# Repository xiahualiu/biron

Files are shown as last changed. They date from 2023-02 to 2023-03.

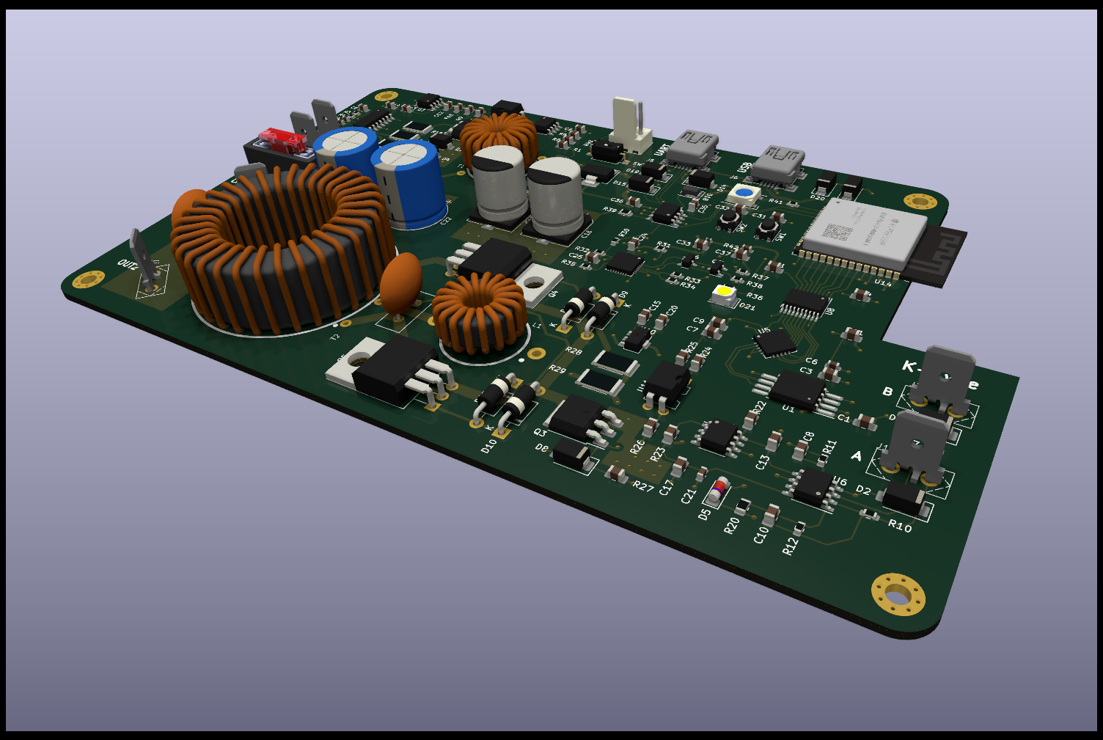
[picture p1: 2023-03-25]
KiCAD/3d/biron.png

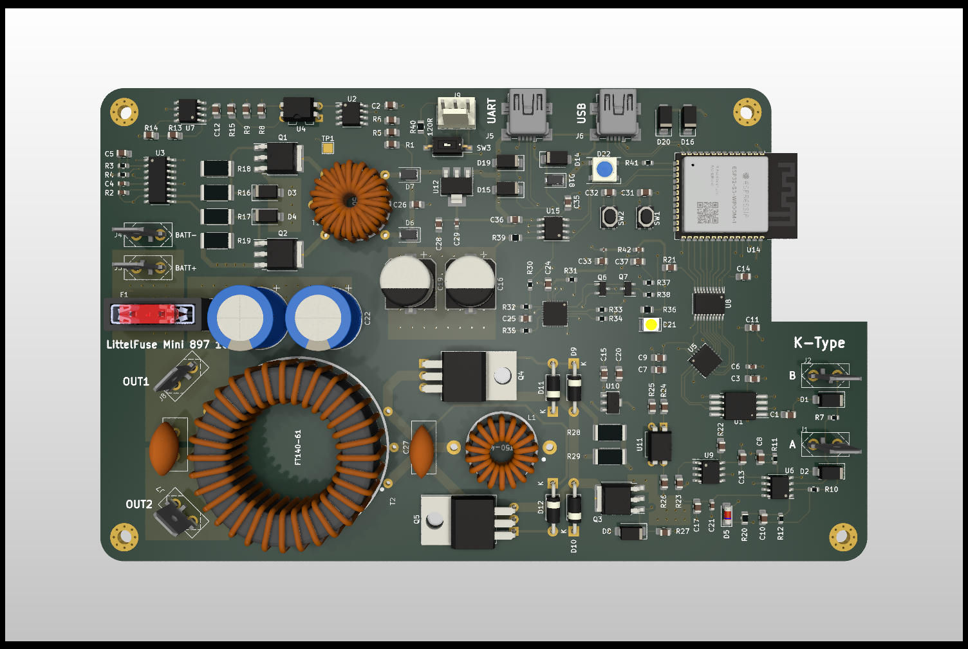
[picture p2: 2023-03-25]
KiCAD/3d/biron-top.png

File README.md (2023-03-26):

# biron

Biron is an open source soldering iron hardware based on Baxandall Oscillator. This is a homebrew project that I am doing during the free time at home.

## Software Requirements

* KiCAD v7.0.0 or above to view the schematic and PCB files.
* LTSpice 17.1.6.0 or above to view the SPICE simulation.

## Disclaimer

This is an open source project that involves high voltage and hot surfaces. You must have enough experience to build it in real life and wear PPE, I don't want people get hurt.

result





This project follows the Ti's [DAQ system requirements](https://www.ti.com/solution/data-acquisition-daq), the control system is fully galvanized isolated from the physical and power signals.



### Power isolation

I used a minimal push-pull converter for the DC/DC part:



### Sensor signal isolation

Sensor signals are amplifier through a TL082H (not practical in the real world because of the high Vos, you want Vos<100uV if possible). The signal is read by a RV1S9353A from Renesas.



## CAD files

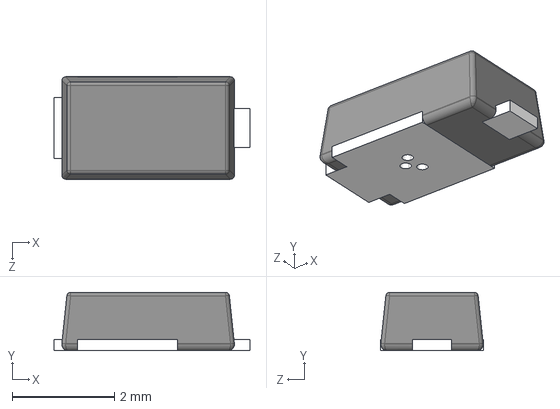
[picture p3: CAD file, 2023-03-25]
KiCAD/3d/SS3P6HM3_85A.STEP
3.83 x 1.14 x 2.00 mm

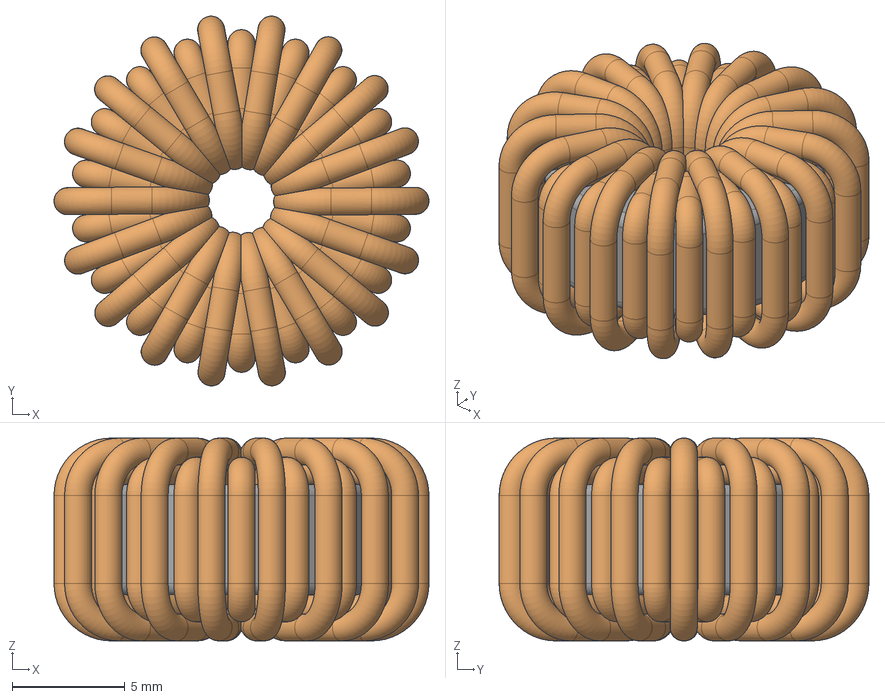
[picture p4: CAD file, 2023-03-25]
KiCAD/3d/FT50-75.step
16.6 x 16.4 x 9.00 mm

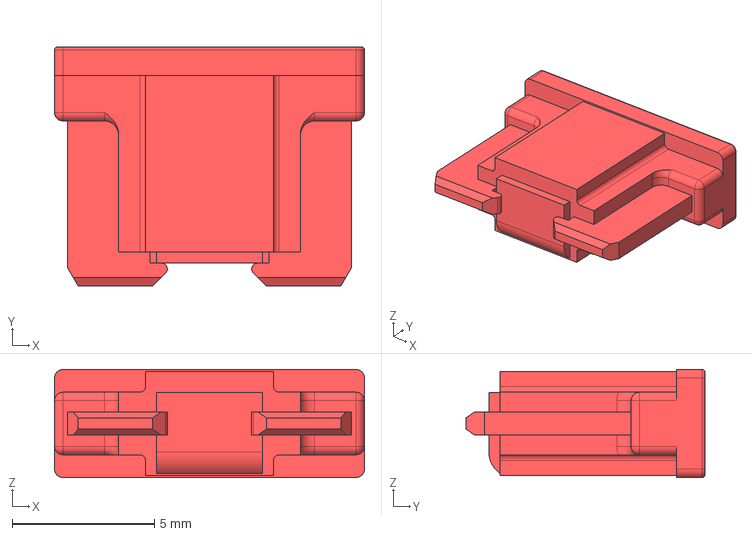
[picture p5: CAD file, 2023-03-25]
KiCAD/3d/Red-3DMODEL_0891000_LPMINI.step
10.9 x 8.40 x 3.80 mm

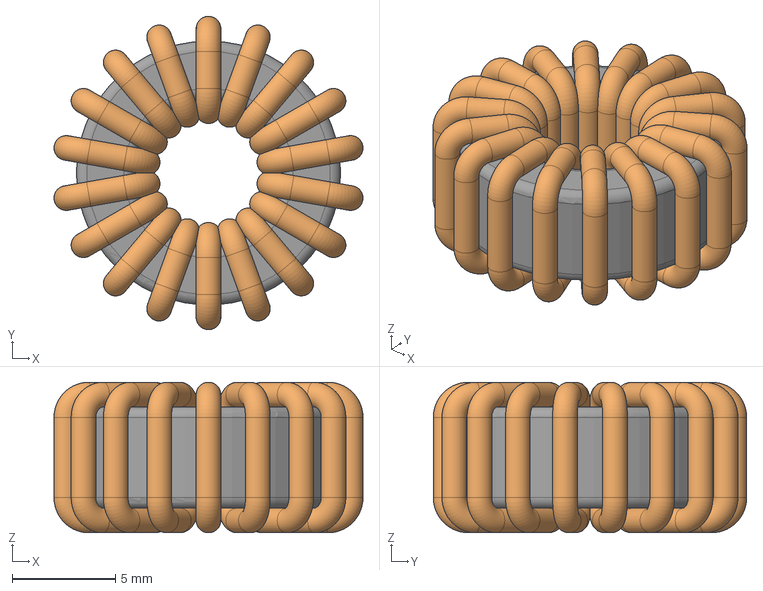
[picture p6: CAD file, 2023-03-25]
KiCAD/3d/FT50-43.step
15.0 x 15.2 x 7.30 mm

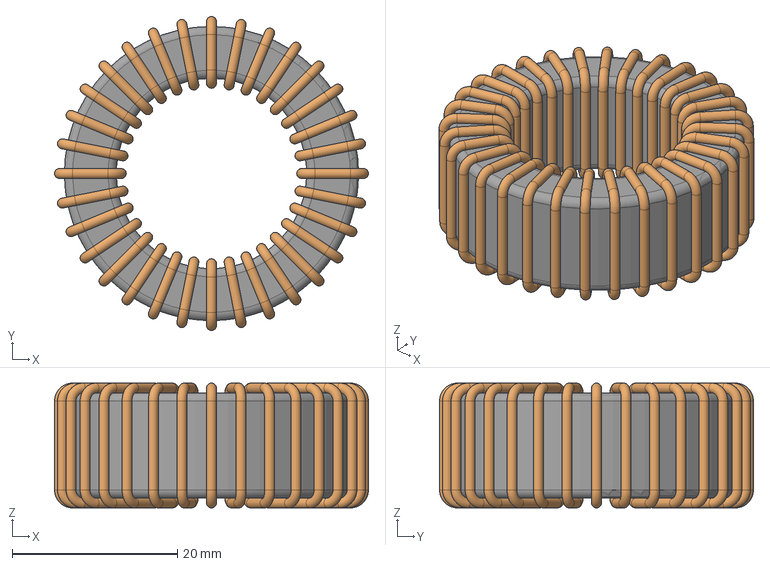
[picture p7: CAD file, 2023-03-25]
KiCAD/3d/FT140-61.step
38.0 x 38.0 x 15.1 mm

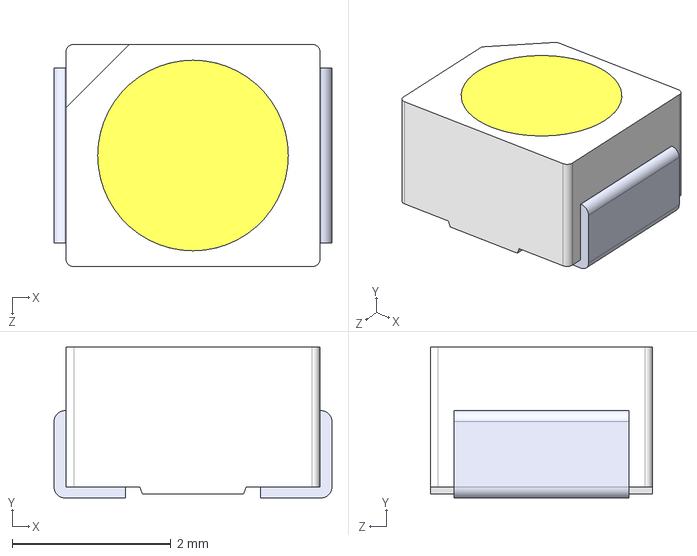
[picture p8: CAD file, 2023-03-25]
KiCAD/3d/OF-SMD3528WC--3DModel-STEP-269445.STEP
3.50 x 1.90 x 2.80 mm

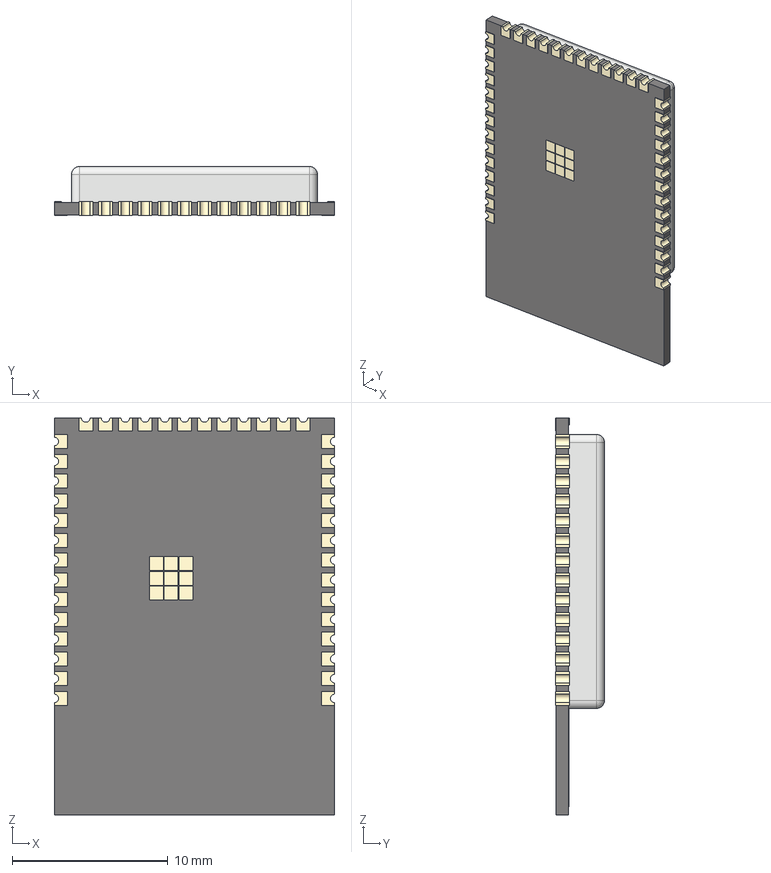
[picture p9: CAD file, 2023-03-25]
KiCAD/3d/ESP32-S3-WROOM.step
18.0 x 3.16 x 25.5 mm
ESP-S3-WROOM_via x 26
ESP32-S3-WROOM_shell
ESP32-S3-WROOM_body
ESP-S3-WROOM_via v3(镜像) x 14

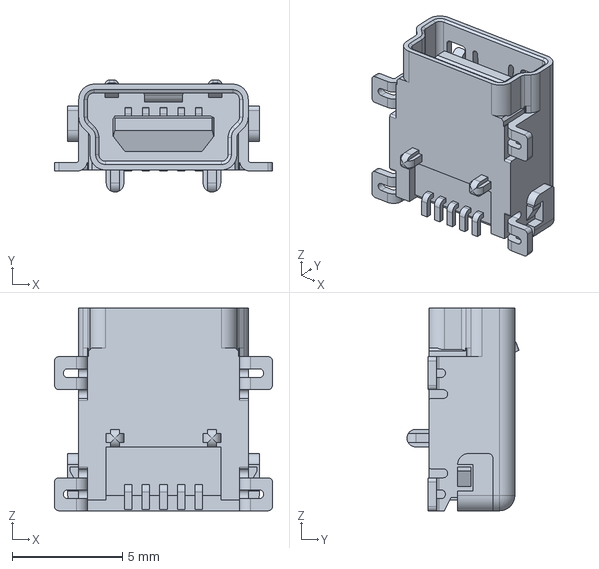
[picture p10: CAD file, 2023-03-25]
KiCAD/3d/3-1734035-2.stp
9.90 x 5.09 x 9.20 mm

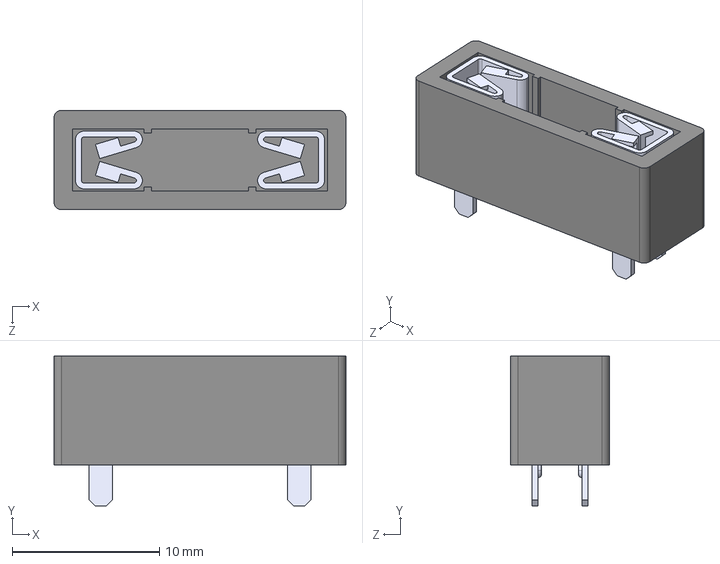
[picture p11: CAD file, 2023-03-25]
KiCAD/3d/3557-2.step
19.8 x 10.2 x 6.73 mm

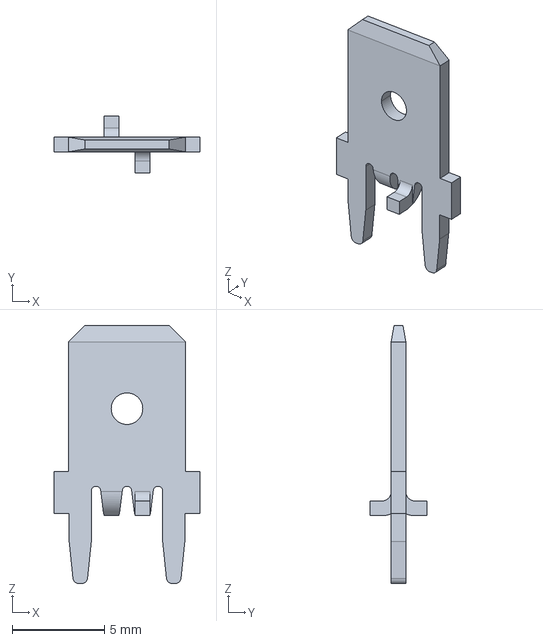
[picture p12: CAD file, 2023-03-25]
KiCAD/3d/63824-1--3DModel-STEP-1.STEP
7.92 x 3.09 x 14.0 mm

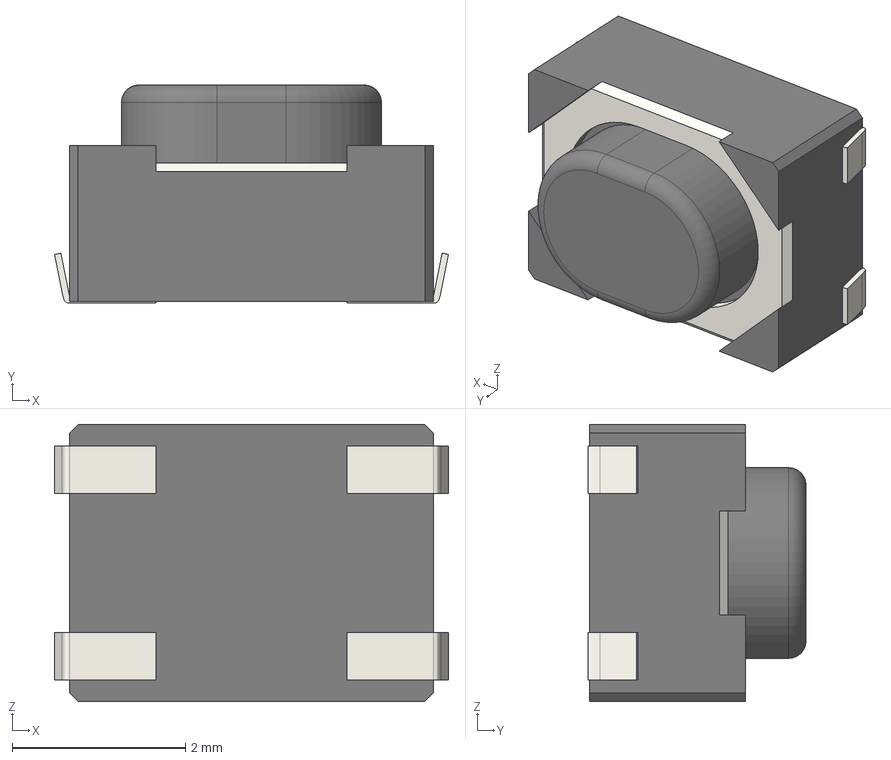
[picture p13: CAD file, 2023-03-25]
KiCAD/3d/434133025816--3DModel-STEP-209312.STEP
4.55 x 2.52 x 3.20 mm

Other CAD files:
KiCAD/3d/3D_model_0891000_LP_MINI_58V.stp
KiCAD/3d/FT140-61.FCStd
KiCAD/3d/FT50-43.FCStd
KiCAD/3d/FT50-75.FCStd

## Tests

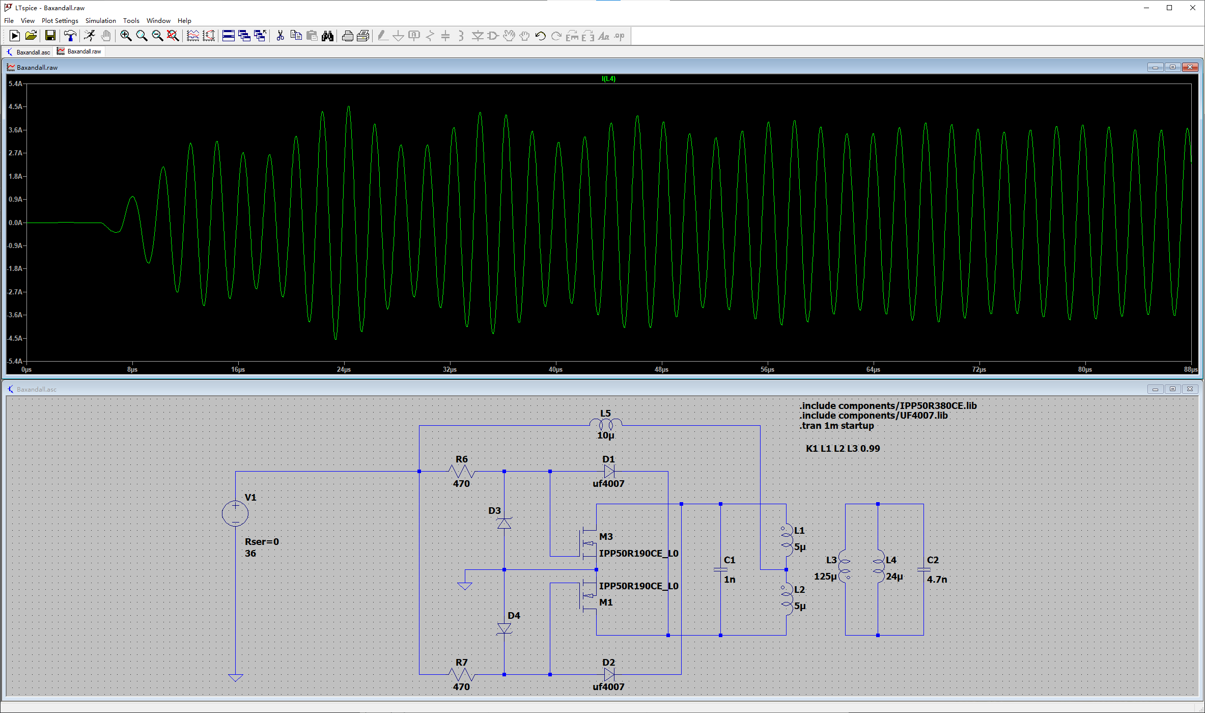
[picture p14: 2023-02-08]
LTSpice/result.png

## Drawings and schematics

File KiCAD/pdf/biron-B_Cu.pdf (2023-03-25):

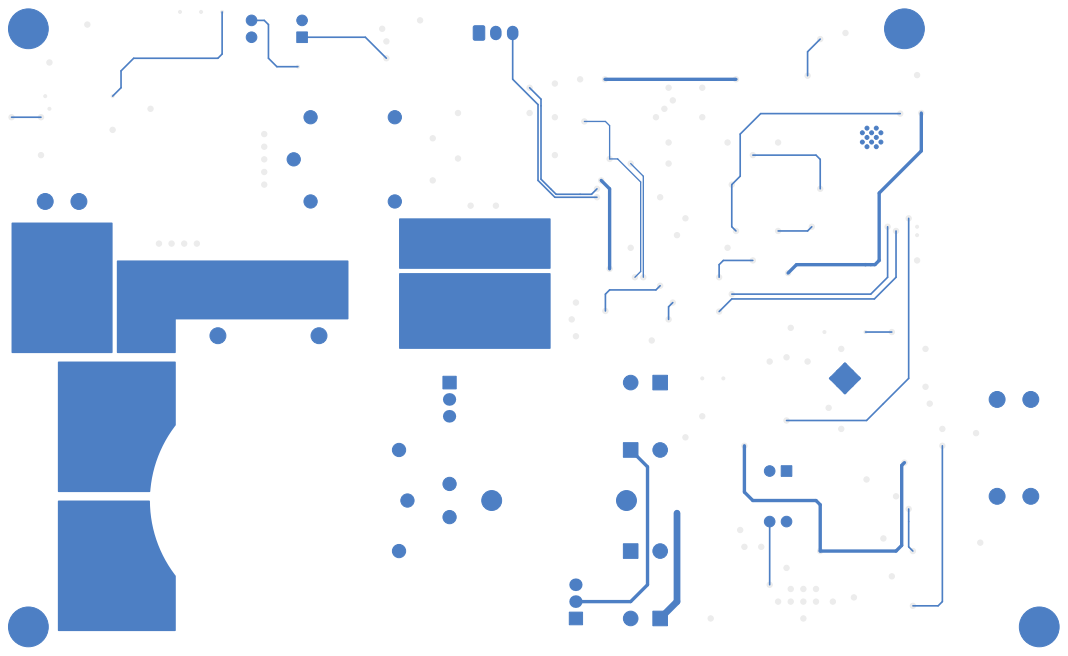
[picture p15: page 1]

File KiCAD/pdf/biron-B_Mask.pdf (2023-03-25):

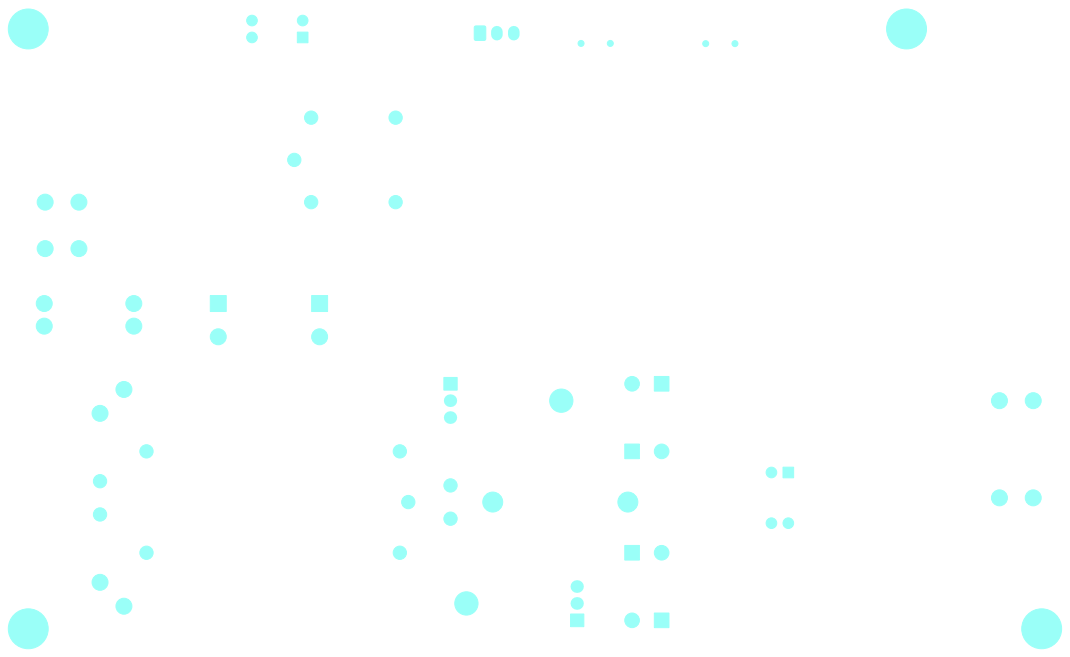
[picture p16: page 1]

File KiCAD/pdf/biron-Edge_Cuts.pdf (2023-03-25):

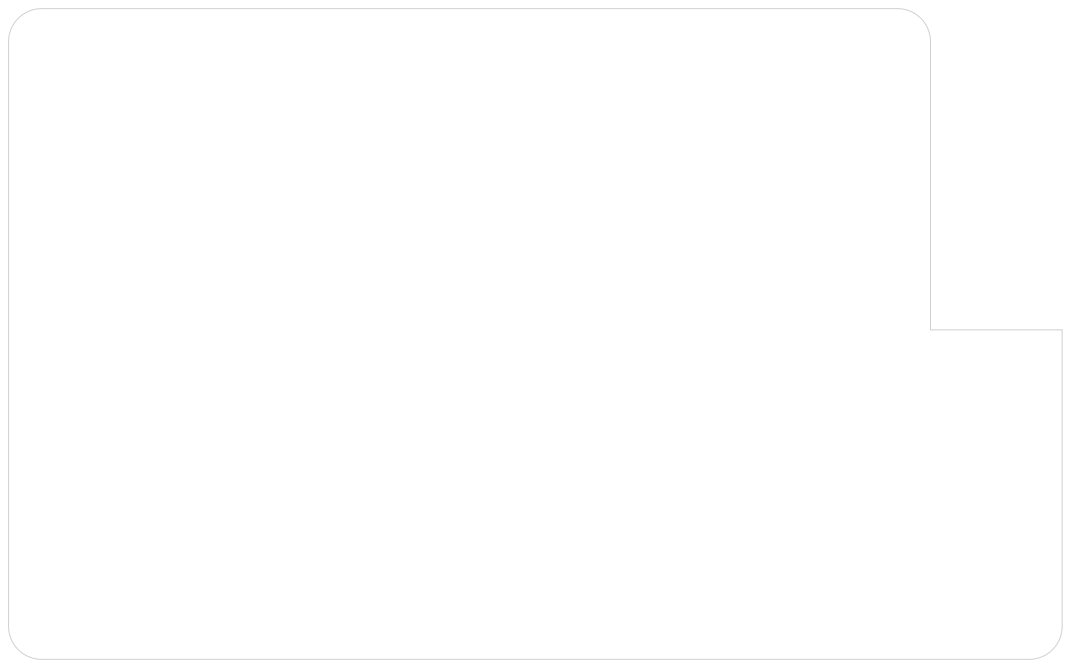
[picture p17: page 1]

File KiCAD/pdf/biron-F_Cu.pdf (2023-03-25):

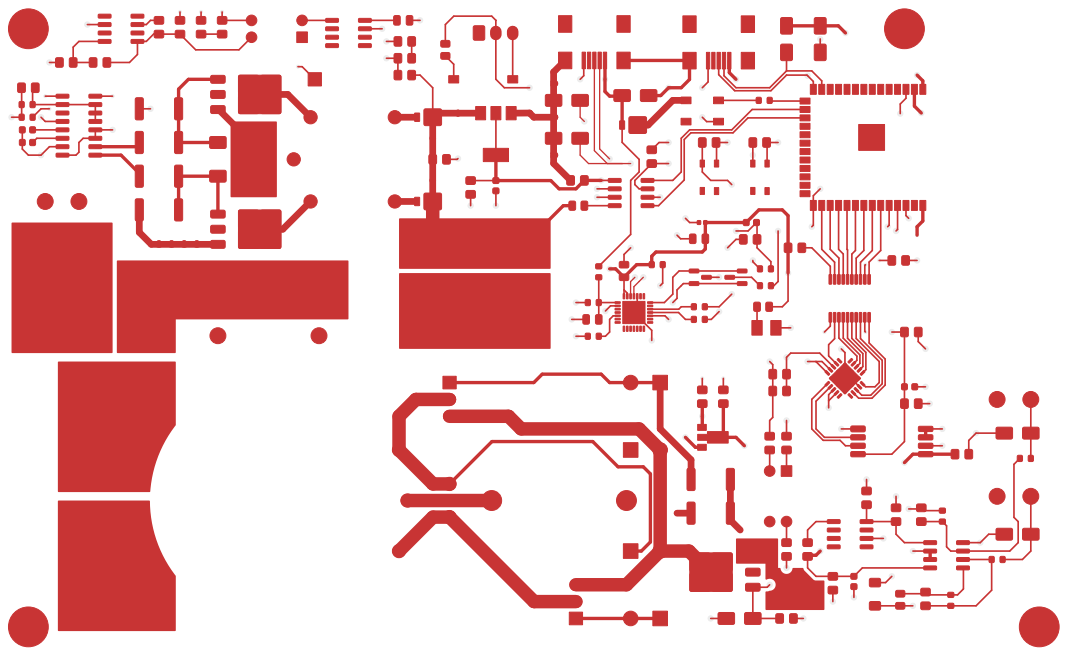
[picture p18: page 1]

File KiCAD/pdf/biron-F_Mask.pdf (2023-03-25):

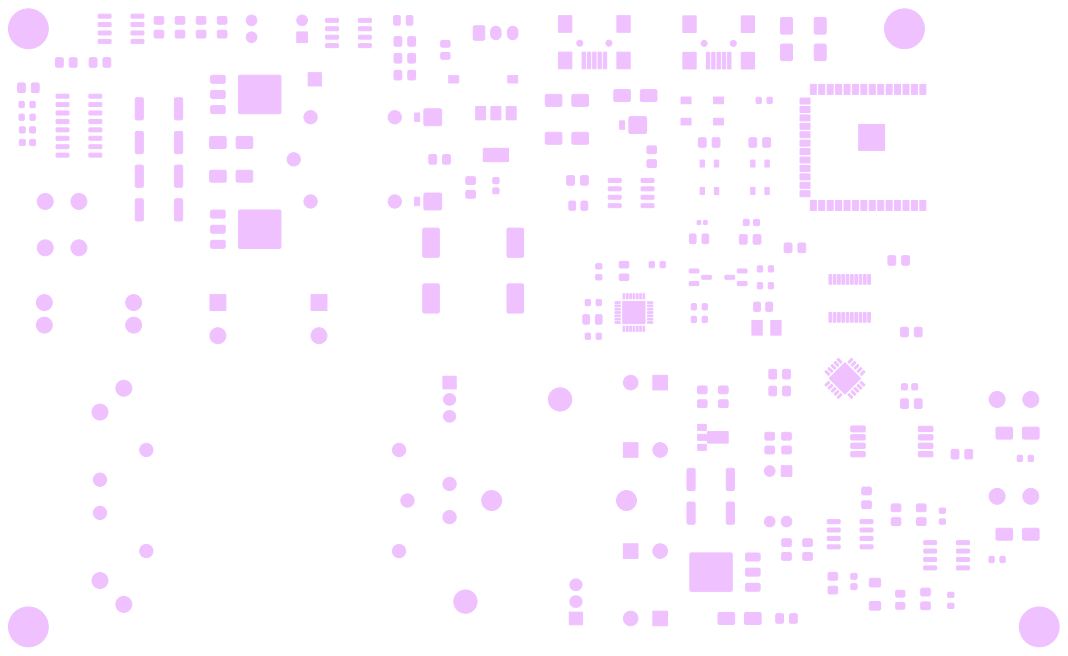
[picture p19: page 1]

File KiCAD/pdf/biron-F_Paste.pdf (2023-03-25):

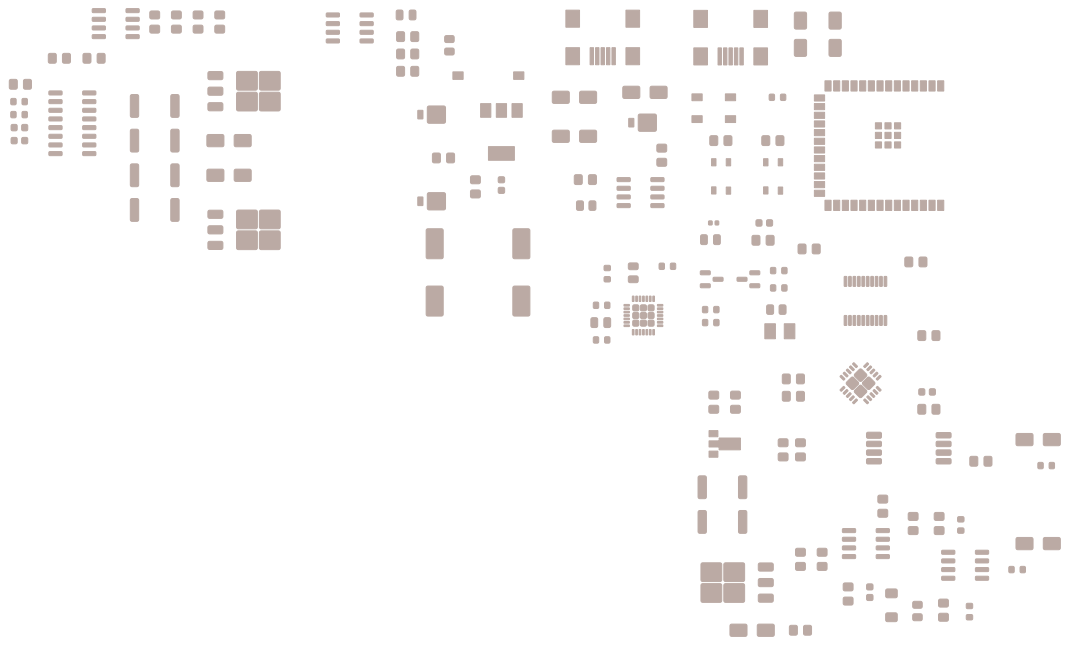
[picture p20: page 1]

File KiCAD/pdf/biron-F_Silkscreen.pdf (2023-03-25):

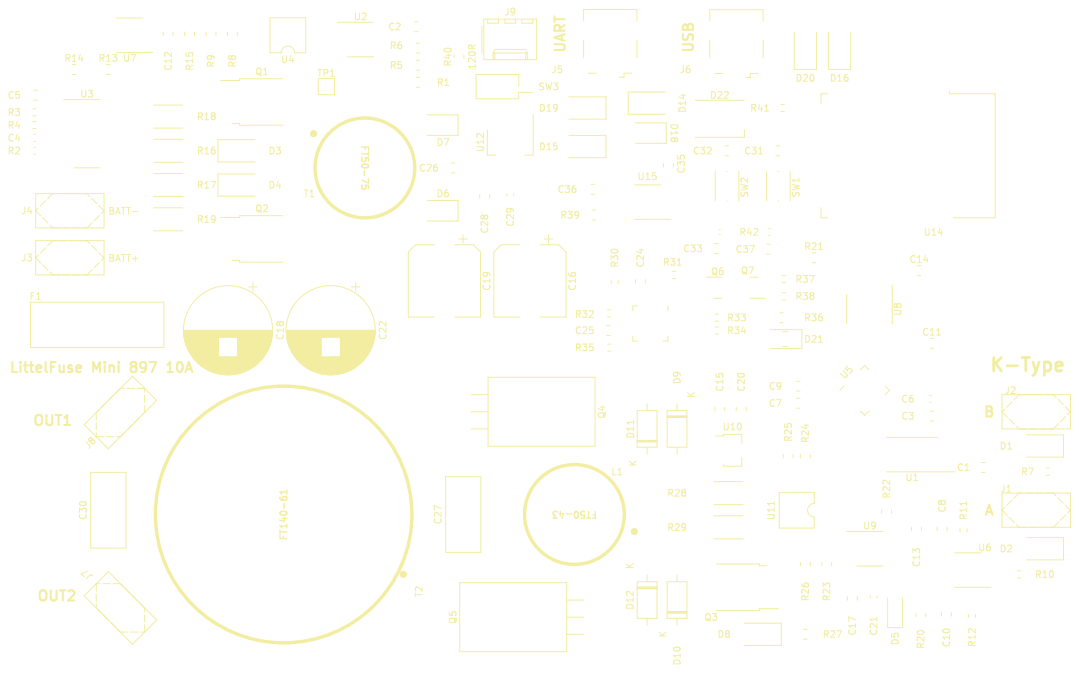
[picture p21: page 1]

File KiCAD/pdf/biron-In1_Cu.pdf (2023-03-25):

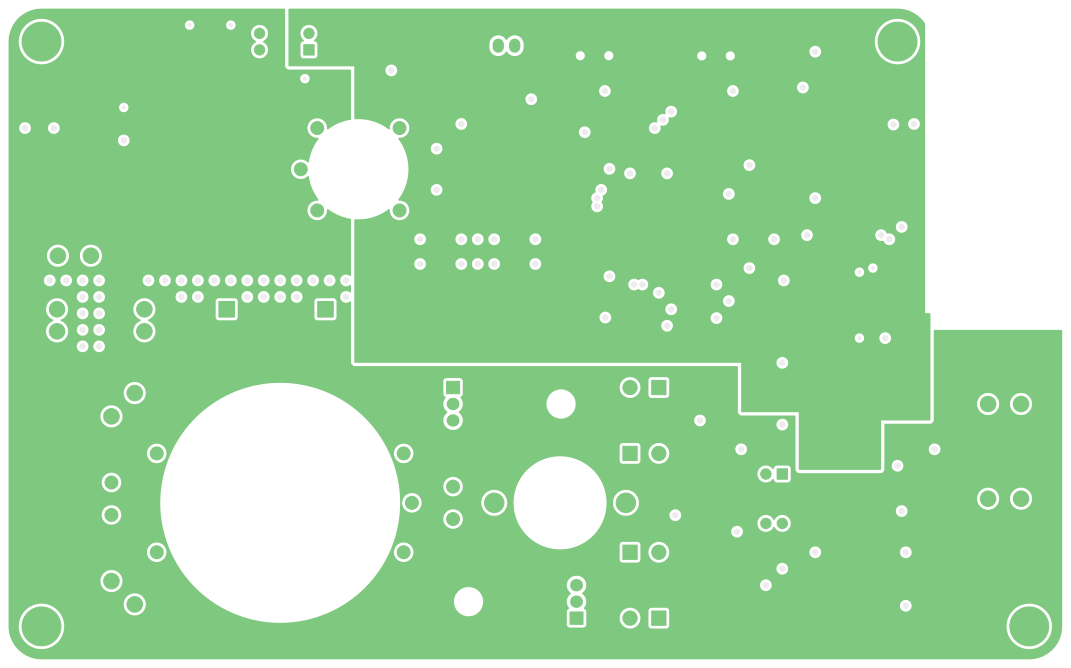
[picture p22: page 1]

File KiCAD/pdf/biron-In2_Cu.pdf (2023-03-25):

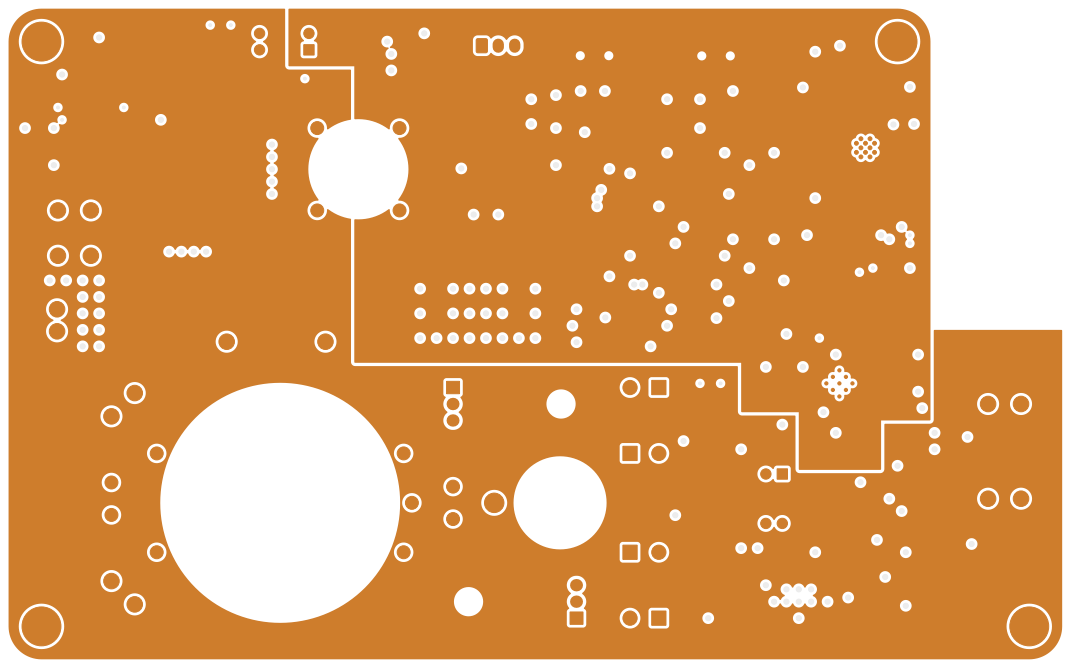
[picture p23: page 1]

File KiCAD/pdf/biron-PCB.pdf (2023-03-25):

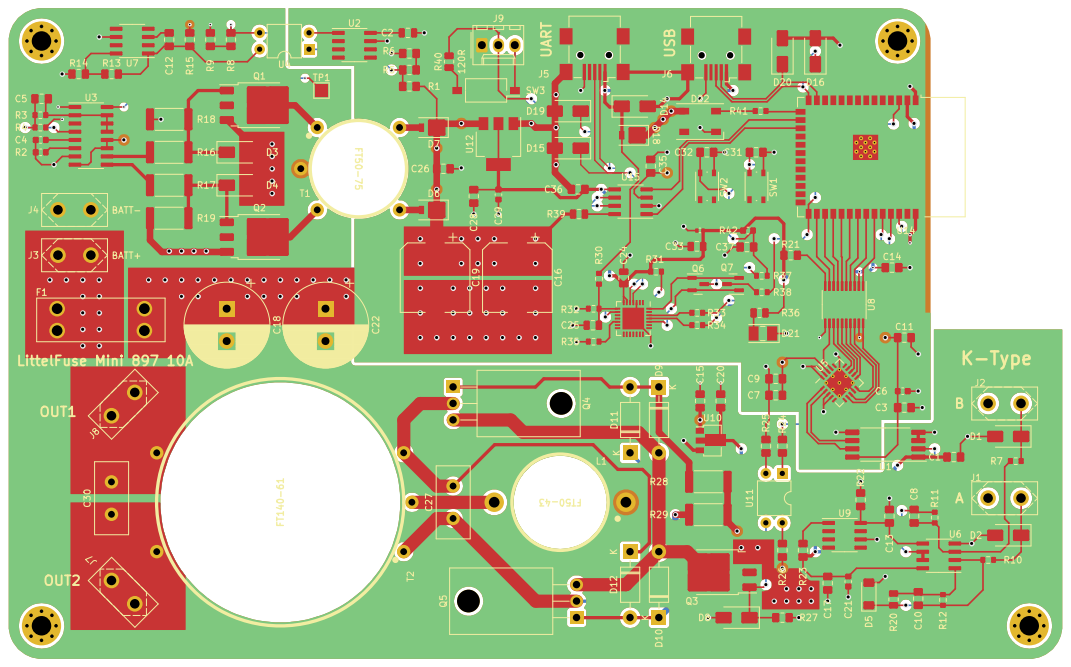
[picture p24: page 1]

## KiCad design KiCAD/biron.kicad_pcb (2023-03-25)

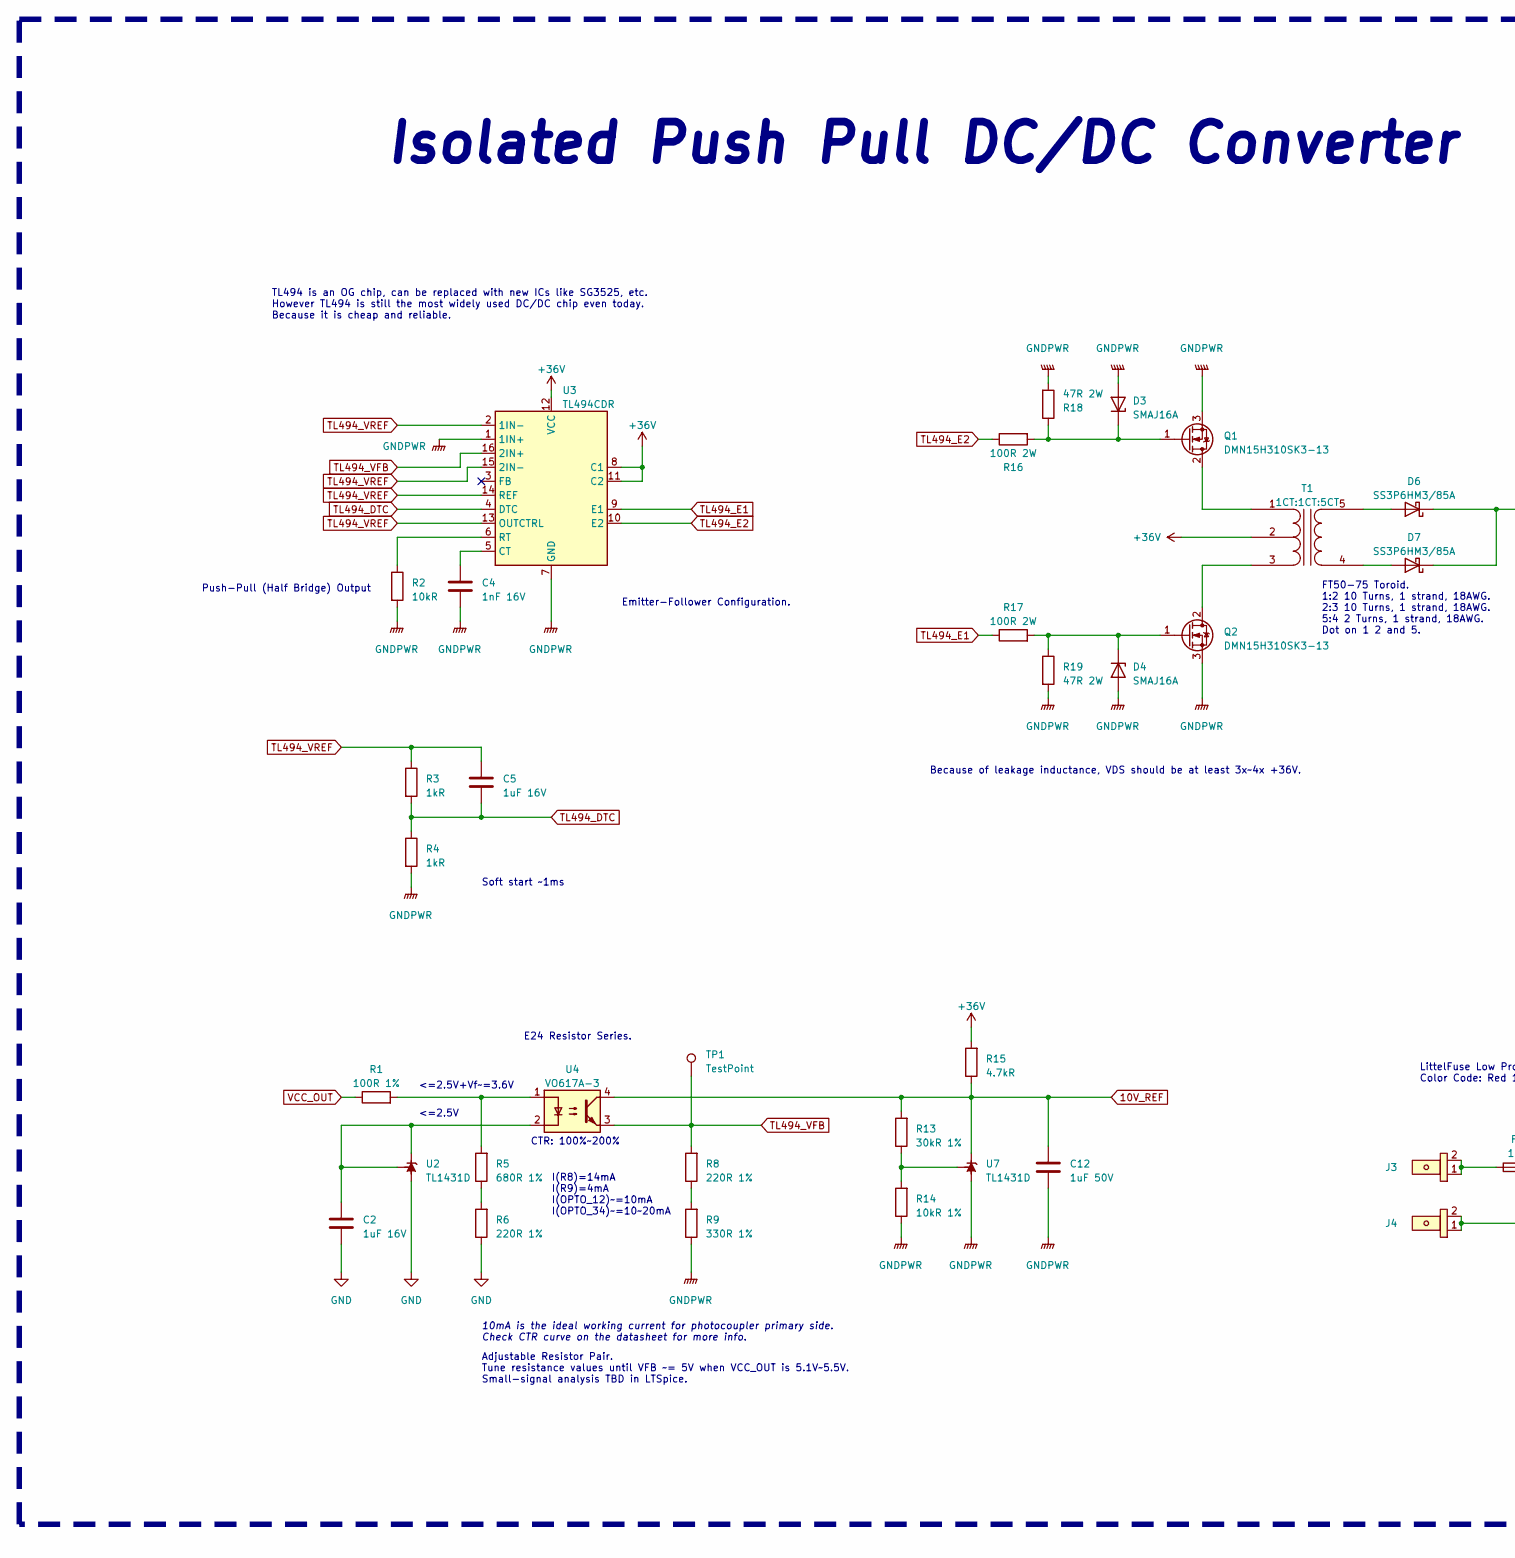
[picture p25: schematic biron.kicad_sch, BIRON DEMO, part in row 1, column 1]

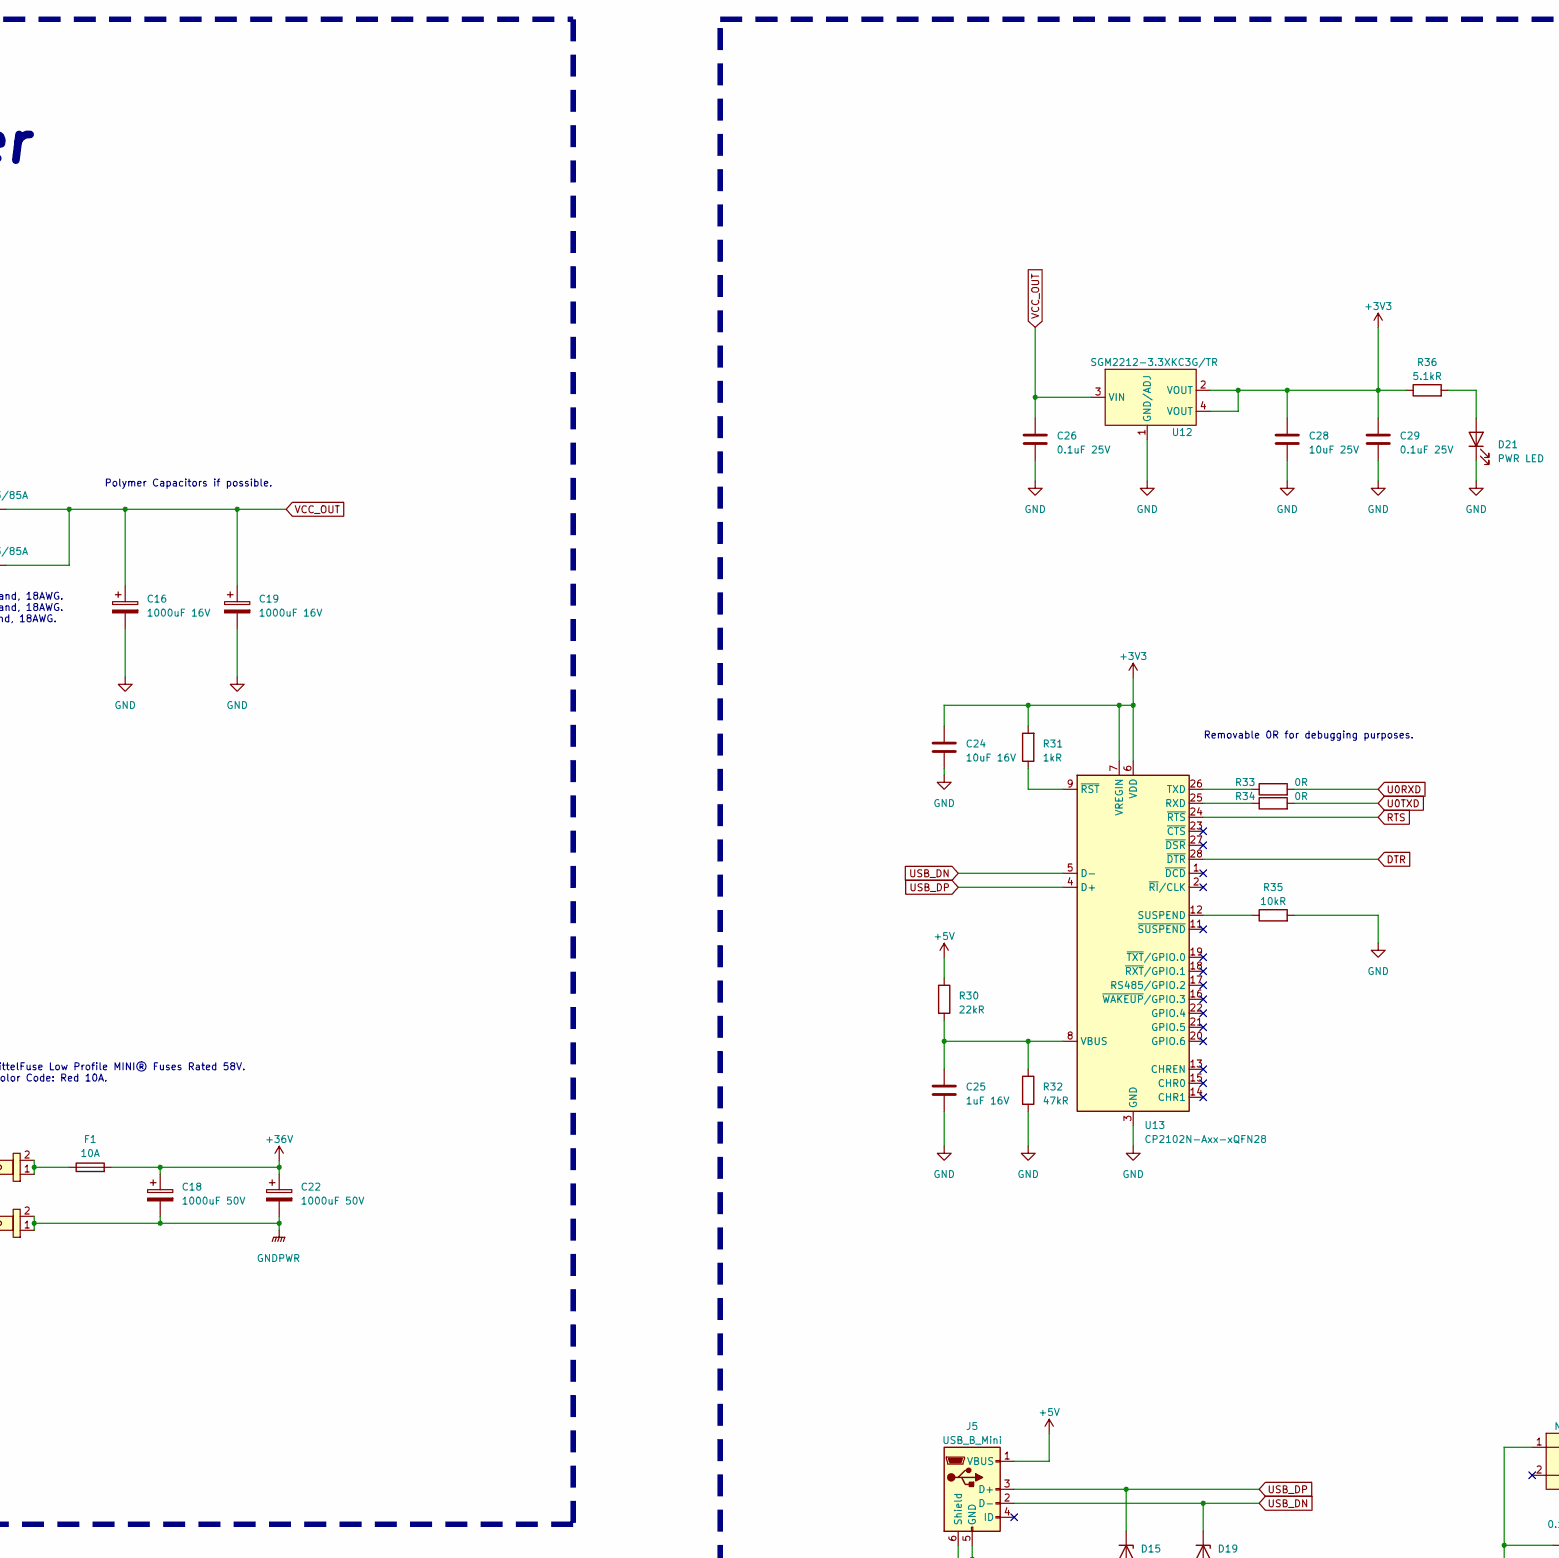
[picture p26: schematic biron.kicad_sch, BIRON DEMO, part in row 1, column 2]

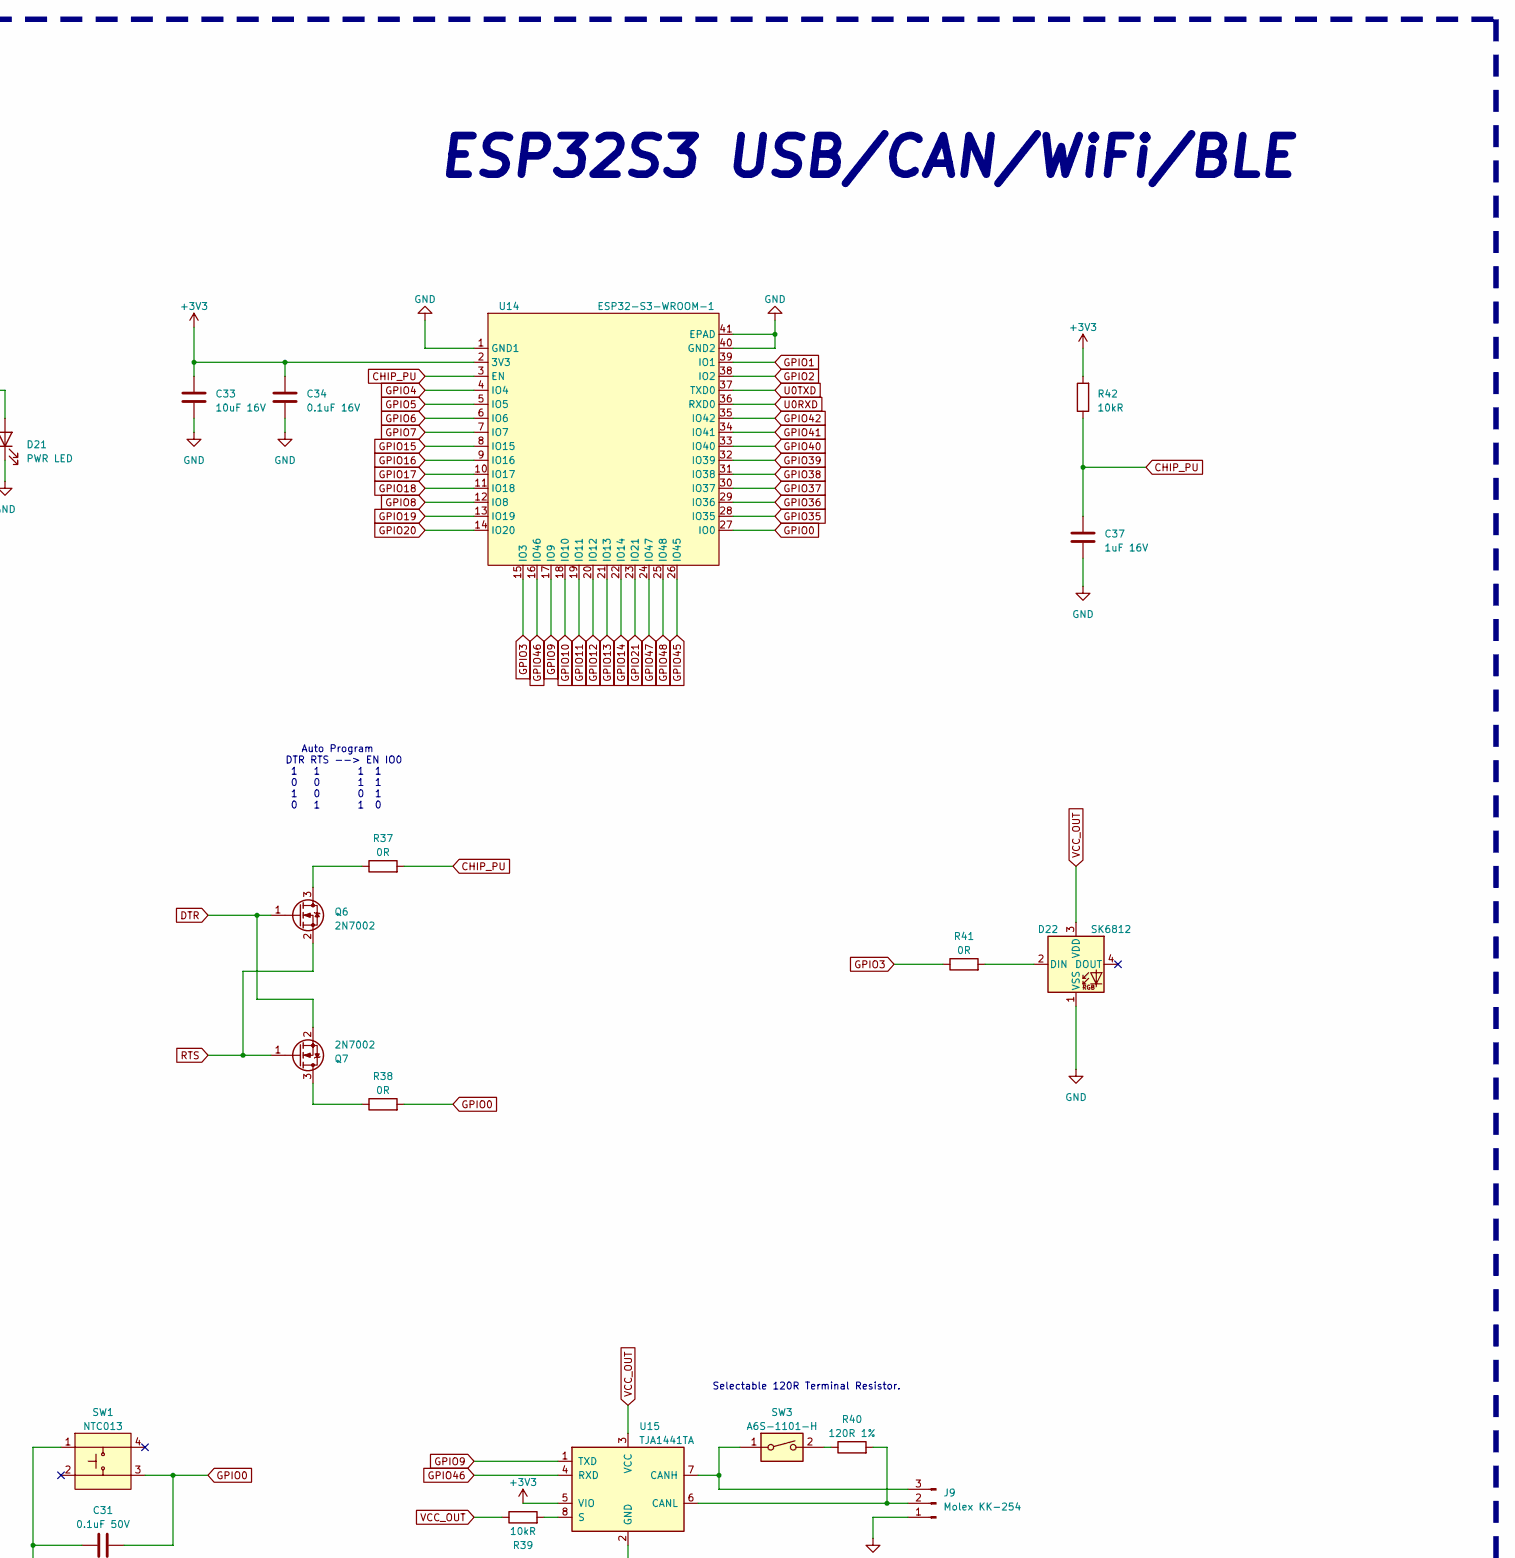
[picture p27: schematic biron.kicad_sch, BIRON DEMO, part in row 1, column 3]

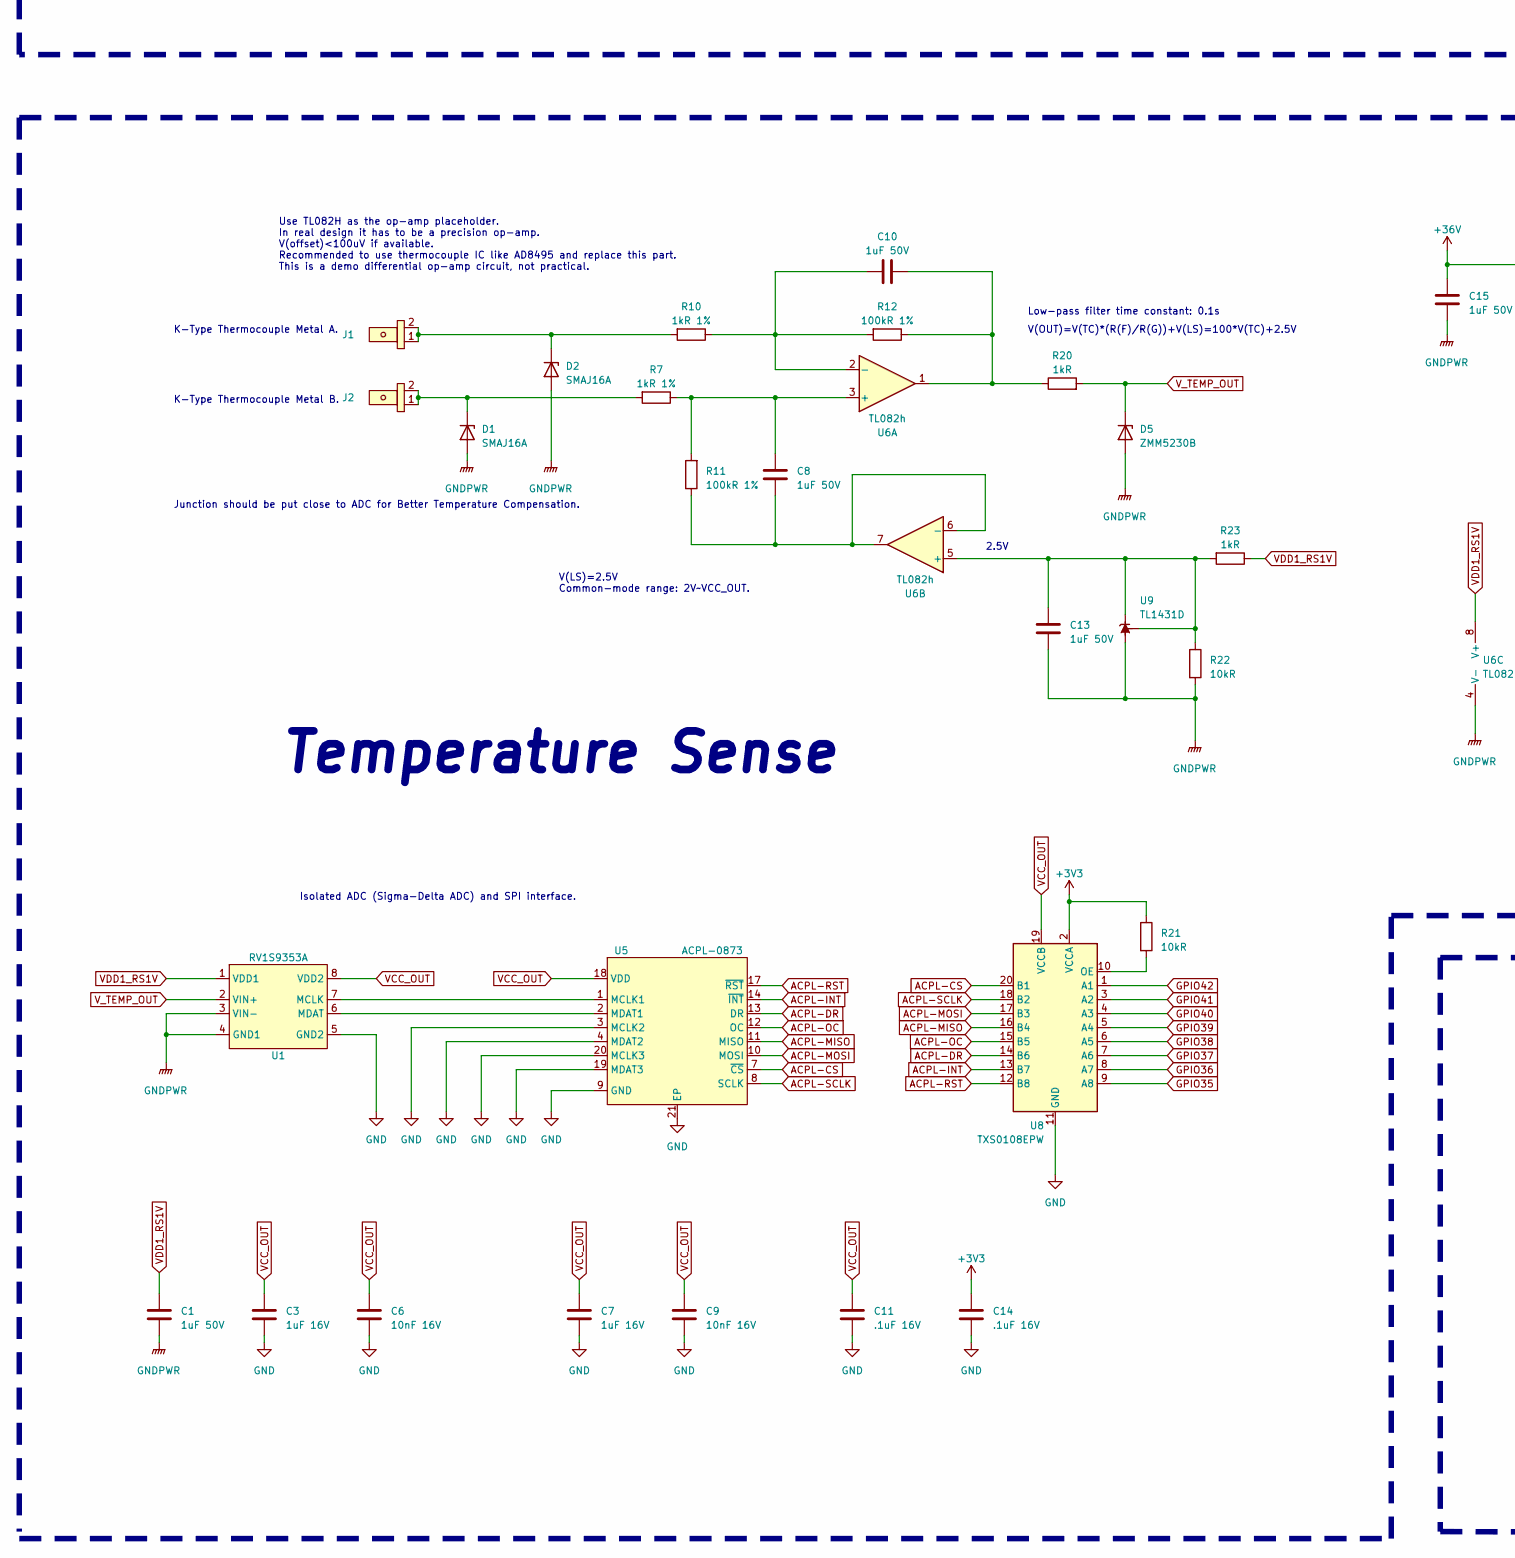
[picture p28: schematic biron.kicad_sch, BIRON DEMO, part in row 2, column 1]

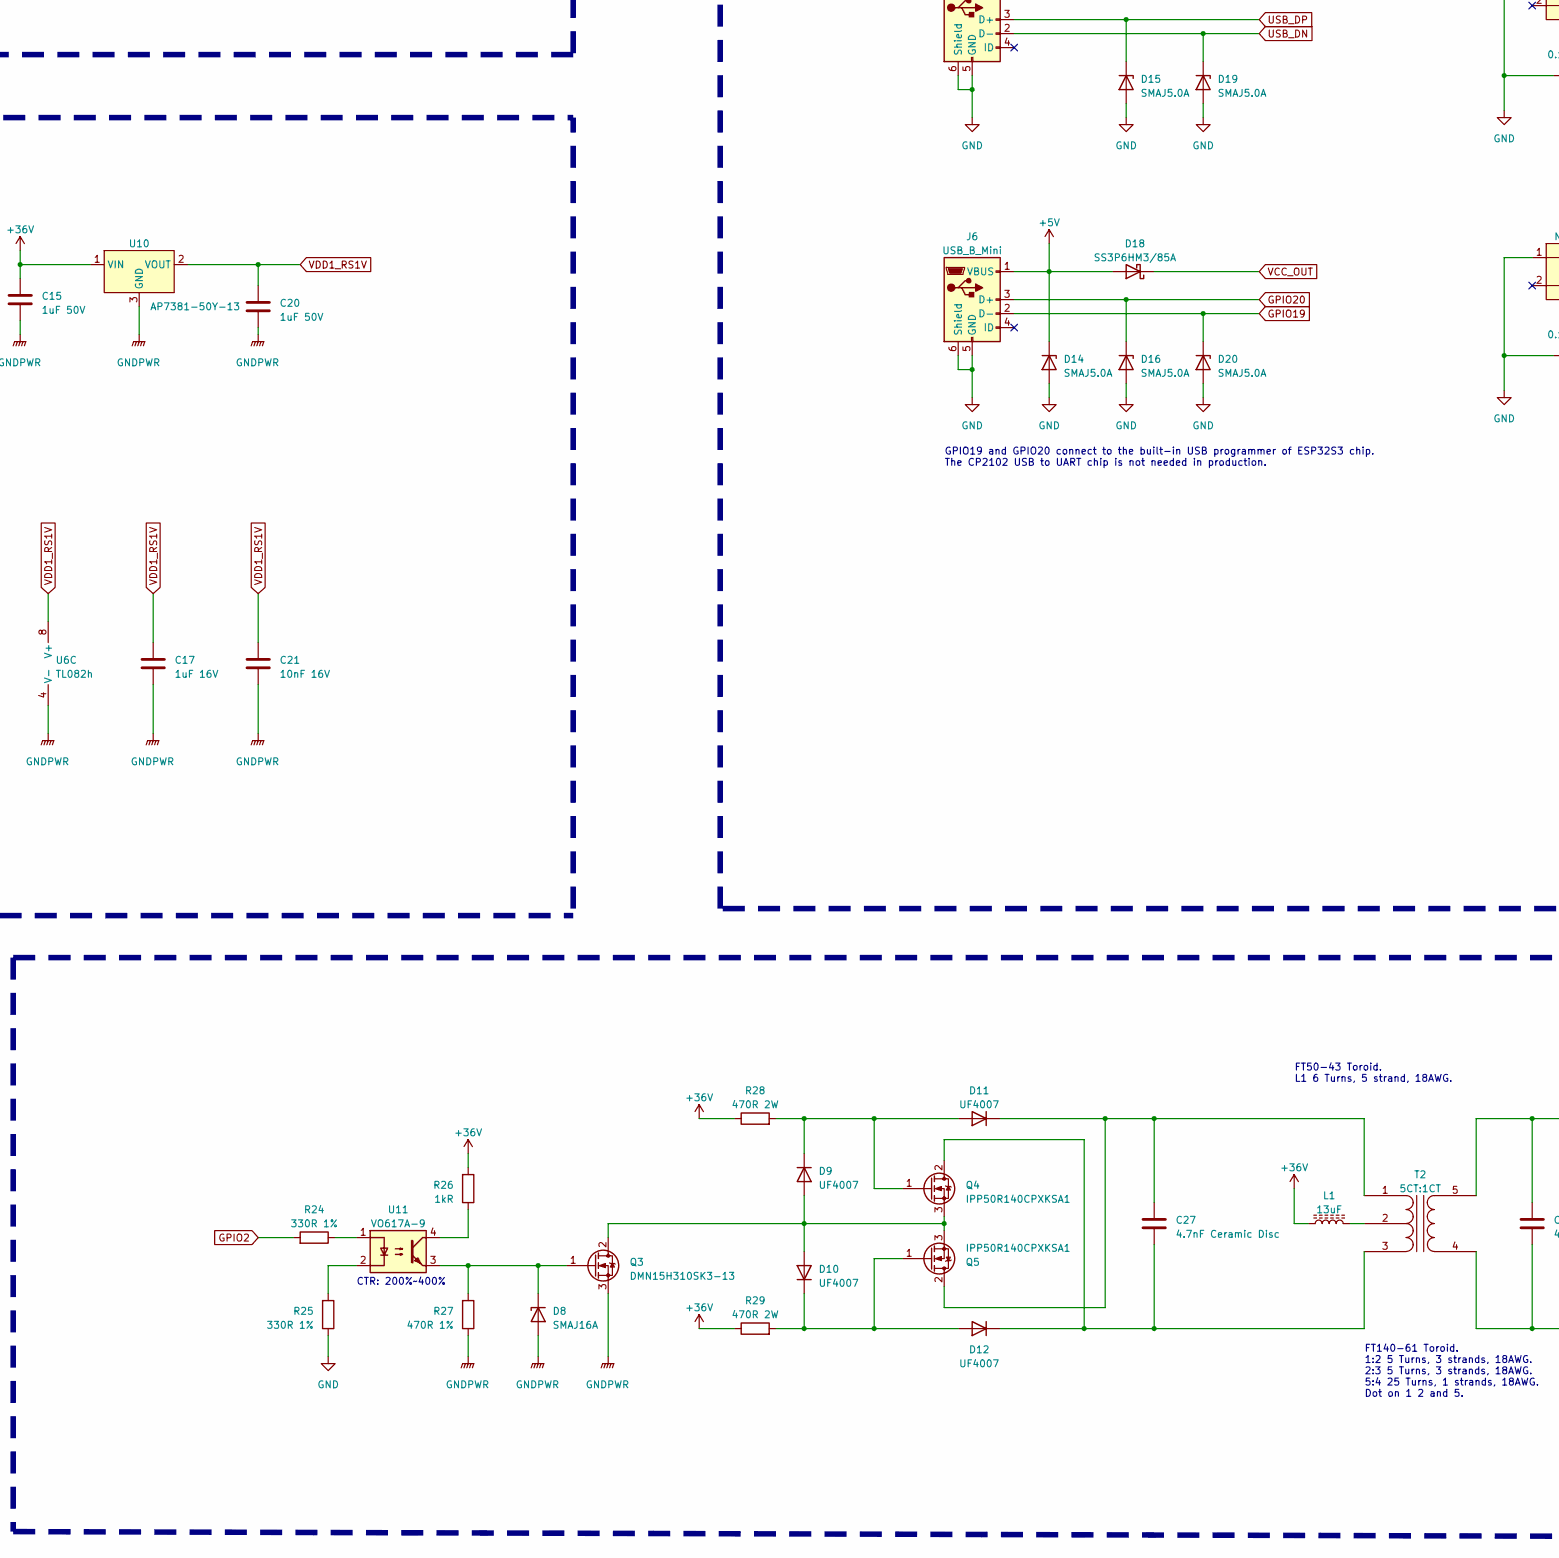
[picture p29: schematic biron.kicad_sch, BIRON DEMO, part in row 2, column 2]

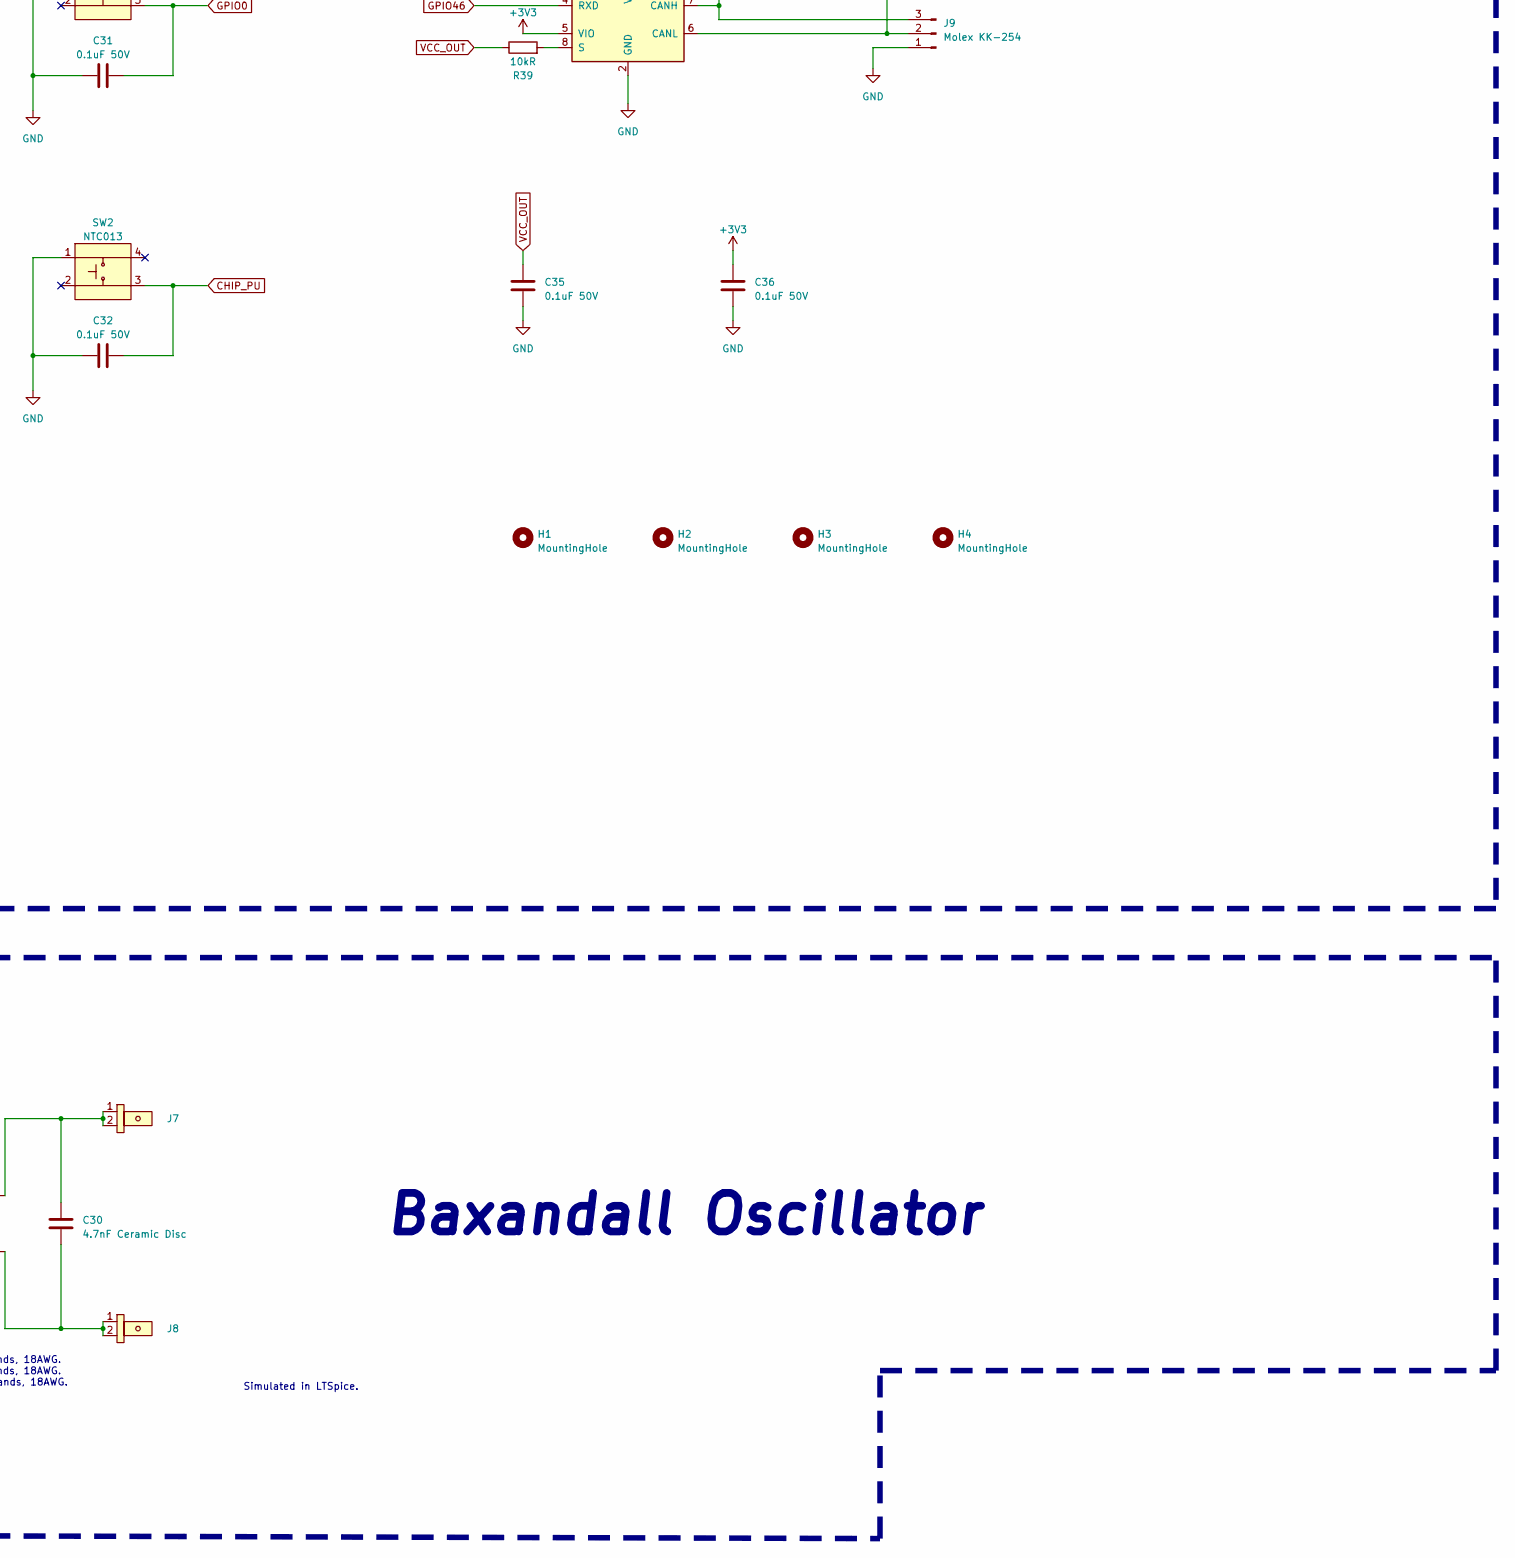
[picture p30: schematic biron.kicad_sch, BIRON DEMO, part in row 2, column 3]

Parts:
C1, C8, C10, C12, C13, C15, C20: 1uF 50V; C_0805_2012Metric_Pad1.18x1.45mm_HandSolder
C2, C25: 1uF 16V; C_0805_2012Metric
C3, C5, C7, C17, C37: 1uF 16V; C_0805_2012Metric_Pad1.18x1.45mm_HandSolder
C4: 1nF 16V; C_0603_1608Metric
C6, C21: 10nF 16V; C_0603_1608Metric
C9: 10nF 16V; C_0805_2012Metric_Pad1.18x1.45mm_HandSolder
C11, C14: .1uF 16V; C_0805_2012Metric_Pad1.18x1.45mm_HandSolder
C16, C19: 1000uF 16V; CP_Elec_10x12.5
C18, C22: 1000uF 50V; CP_Radial_D13.0mm_P5.00mm
C24, C33: 10uF 16V; C_0805_2012Metric
C26: 0.1uF 25V; C_0805_2012Metric_Pad1.18x1.45mm_HandSolder
C27, C30: 4.7nF Ceramic Disc; C_Disc_D11.0mm_W5.0mm_P5.00mm
C28: 10uF 25V; C_0805_2012Metric_Pad1.18x1.45mm_HandSolder
C29: 0.1uF 25V; C_0603_1608Metric
C31, C32, C35, C36: 0.1uF 50V; C_0805_2012Metric_Pad1.18x1.45mm_HandSolder
C34: 0.1uF 16V; C_0402_1005Metric
D1, D2, D3, D4, D8: SMAJ16A; D_SMA
D5: ZMM5230B; D_MiniMELF
D6, D7, D18: SS3P6HM3/85A; DO-220AA
D9, D10, D11, D12: UF4007; D_DO-41_SOD81_P10.16mm_Horizontal
D14, D15, D16, D19, D20: SMAJ5.0A; D_SMA
D21: PWR LED; LED_PLCC-2_3x2mm_KA
D22: SK6812; LED_SK6812_PLCC4_5.0x5.0mm_P3.2mm
F1: 10A; FUSE_3557-2
H1, H2, H3, H4: MountingHole; MountingHole_3mm_Pad_Via
J1, J2, J3, J4, J7, J8: 1217861
J5, J6: USB_B_Mini; USB_Mini-B_Wuerth_65100516121_Horizontal
J9: Molex KK-254; Molex_KK-254_AE-6410-03A_1x03_P2.54mm_Vertical
L1: 13uF; FT50-43
Q1, Q2, Q3: DMN15H310SK3-13; TO-252-3_TabPin2
Q4, Q5: IPP50R140CPXKSA1; TO-220-3_Horizontal_TabDown
Q6, Q7: 2N7002; SOT-23
R1: 100R 1%; C_0805_2012Metric_Pad1.18x1.45mm_HandSolder
R2, R42: 10kR; C_0603_1608Metric
R3, R4, R31: 1kR; R_0603_1608Metric
R5: 680R 1%; C_0805_2012Metric_Pad1.18x1.45mm_HandSolder
R6, R8: 220R 1%; C_0805_2012Metric_Pad1.18x1.45mm_HandSolder
R7, R10: 1kR 1%; R_0603_1608Metric
R9, R24, R25: 330R 1%; C_0805_2012Metric_Pad1.18x1.45mm_HandSolder
R11, R12: 100kR 1%; R_0603_1608Metric
R13: 30kR 1%; C_0805_2012Metric_Pad1.18x1.45mm_HandSolder
R14: 10kR 1%; C_0805_2012Metric_Pad1.18x1.45mm_HandSolder
R15: 4.7kR; C_0805_2012Metric_Pad1.18x1.45mm_HandSolder
R16, R17: 100R 2W; R_2512_6332Metric
R18, R19: 47R 2W; R_2512_6332Metric
R20: 1kR; R_0805_2012Metric
R21, R22: 10kR; C_0805_2012Metric_Pad1.18x1.45mm_HandSolder
R23, R26: 1kR; C_0805_2012Metric_Pad1.18x1.45mm_HandSolder
R27: 470R 1%; C_0805_2012Metric_Pad1.18x1.45mm_HandSolder
R28, R29: 470R 2W; R_2512_6332Metric
R30: 22kR; R_0603_1608Metric
R32: 47kR; R_0603_1608Metric
R33, R34, R37, R38, R41: 0R; R_0603_1608Metric
R35: 10kR; R_0603_1608Metric
R36: 5.1kR; R_0805_2012Metric
R39: 10kR; R_0805_2012Metric
R40: 120R 1%; R_0805_2012Metric
SW1, SW2: NTC013; SW_Push_1P1T_NO_Vertical_Wuerth_434133025816
SW3: A6S-1101-H; SW_DIP_SPSTx01_Slide_Omron_A6S-110x_W8.9mm_P2.54mm
T1: 1CT:1CT:5CT; FT50-75
T2: 5CT:1CT; FT140-61
TP1: TestPoint; TestPoint_Pad_2.0x2.0mm
U1: RV1S9353A
U2, U7, U9: TL1431D; SOIC-8_3.9x4.9mm_P1.27mm
U3: TL494CDR; SOIC-16_3.9x9.9mm_P1.27mm
U4: VO617A-3; DIP-4_W7.62mm
U5: ACPL-0873; QFN-20-1EP_5x5mm_P0.65mm_EP3.35x3.35mm_ThermalVias
U6: TL082h; SOIC-8_3.9x4.9mm_P1.27mm
U8: TXS0108EPW; TSSOP-20_4.4x6.5mm_P0.65mm
U10: AP7381-50Y-13; SOT-89-3
U11: VO617A-9; DIP-4_W7.62mm
U12: SGM2212-3.3XKC3G/TR; SOT-223
U13: CP2102N-Axx-xQFN28; QFN-28-1EP_5x5mm_P0.5mm_EP3.35x3.35mm
U14: ESP32-S3-WROOM-1
U15: TJA1441TA; SOIC-8_3.9x4.9mm_P1.27mm

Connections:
10V_REF: C12.1, R13.2, R15.1, U4.4, U7.1 (K)
+3V3: C14.1, C24.1, C28.1, C29.1, C33.1, C34.1, C36.2, R21.1, R31.2, R36.1, R42.2, U8.2 (VCCA), U12.2 (VOUT), U12.4 (VOUT), U13.6 (VDD), U13.7 (VREGIN), U14.2 (3V3), U15.5 (VIO)
+5V: D14.1 (K), D18.2 (A), J5.1 (VBUS), J6.1 (VBUS), R30.1
+36V: C15.1, C18.1, C22.1, F1.2, L1.1, R15.2, R26.2, R28.1, R29.1, T1.2 (PM), U3.8 (C1), U3.11 (C2), U3.12 (VCC), U10.1 (VIN)
ACPL-CS: U5.7 (~CS), U8.20 (B1)
ACPL-DR: U5.13 (DR), U8.14 (B6)
ACPL-INT: U5.14 (~INT), U8.13 (B7)
ACPL-MISO: U5.11 (MISO), U8.16 (B4)
ACPL-MOSI: U5.10 (MOSI), U8.17 (B3)
ACPL-OC: U5.12 (OC), U8.15 (B5)
ACPL-RST: U5.17 (~RST), U8.12 (B8)
ACPL-SCLK: U5.8 (SCLK), U8.18 (B2)
CHIP_PU: C32.2, C37.1, R37.2, R42.1, SW2.3, U14.3 (EN)
DTR: Q6.1 (G), Q7.2 (S), U13.28 (~DTR)
GND: C2.2, C3.2, C6.2, C7.2, C9.2, C11.2, C14.2, C16.2, C19.2, C24.2, C25.2, C26.2, C28.2, C29.2, C31.1, C32.1, C33.2, C34.2, C35.1, C36.1, C37.2, D14.2 (A), D15.2 (A), D16.2 (A), D19.2 (A), D20.2 (A), D21.1 (K), D22.1 (VSS), J5.5 (GND), J5.6 (Shield), J6.5 (GND), J6.6 (Shield), J9.1, R6.1, R25.1, R32.2, R35.2, SW1.1, SW2.1, U1.5 (GND2), U2.2 (A), U2.3 (A), U2.6 (A), U2.7 (A), U5.3 (MCLK2), U5.4 (MDAT2), U5.9 (GND), U5.19 (MDAT3), U5.20 (MCLK3), U5.21 (EP), U8.11 (GND), U12.1 (GND/ADJ), U13.3 (GND), U13.29 (GND), U14.1 (GND1), U14.40 (GND2), U14.41 (EPAD), U15.2 (GND)
GNDPWR: C1.2, C4.2, C12.2, C13.2, C15.2, C17.2, C18.2, C20.2, C21.2, C22.2, D1.2 (A), D2.2 (A), D3.2 (A), D4.2 (A), D5.2 (A), D8.2 (A), J4.1, J4.2, Q1.3 (S), Q2.3 (S), Q3.3 (S), R2.2, R4.2, R9.1, R14.1, R18.2, R19.2, R22.2, R27.1, U1.3 (VIN-), U1.4 (GND1), U3.1 (1IN+), U3.7 (GND), U6.4 (V-), U7.2 (A), U7.3 (A), U7.6 (A), U7.7 (A), U9.2 (A), U9.3 (A), U9.6 (A), U9.7 (A), U10.3 (GND)
GPIO0: C31.2, R38.2, SW1.3, U14.27 (IO0)
GPIO1: U14.39 (IO1)
GPIO2: R24.2, U14.38 (IO2)
GPIO3: R41.1, U14.15 (IO3)
GPIO4: U14.4 (IO4)
GPIO5: U14.5 (IO5)
GPIO6: U14.6 (IO6)
GPIO7: U14.7 (IO7)
GPIO8: U14.12 (IO8)
GPIO9: U14.17 (IO9), U15.1 (TXD)
GPIO10: U14.18 (IO10)
GPIO11: U14.19 (IO11)
GPIO12: U14.20 (IO12)
GPIO13: U14.21 (IO13)
GPIO14: U14.22 (IO14)
GPIO15: U14.8 (IO15)
GPIO16: U14.9 (IO16)
GPIO17: U14.10 (IO17)
GPIO18: U14.11 (IO18)
GPIO19: D20.1 (K), J6.2 (D-), U14.13 (IO19)
GPIO20: D16.1 (K), J6.3 (D+), U14.14 (IO20)
GPIO21: U14.23 (IO21)
GPIO35: U8.9 (A8), U14.28 (IO35)
GPIO36: U8.8 (A7), U14.29 (IO36)
GPIO37: U8.7 (A6), U14.30 (IO37)
GPIO38: U8.6 (A5), U14.31 (IO38)
GPIO39: U8.5 (A4), U14.32 (IO39)
GPIO40: U8.4 (A3), U14.33 (IO40)
GPIO41: U8.3 (A2), U14.34 (IO41)
GPIO42: U8.1 (A1), U14.35 (IO42)
GPIO45: U14.26 (IO45)
GPIO46: U14.16 (IO46), U15.4 (RXD)
GPIO47: U14.24 (IO47)
GPIO48: U14.25 (IO48)
unnamed: C10.2, R12.1, R20.1, U6.1
unnamed: D1.1 (K), J2.1, J2.2, R7.2
unnamed: D2.1 (K), J1.1, J1.2, R10.2
unnamed: D3.1 (K), Q1.1 (G), R16.2, R18.1
unnamed: D4.1 (K), Q2.1 (G), R17.2, R19.1
unnamed: D6.2 (A), T1.5 (S2)
unnamed: D7.2 (A), T1.4 (S1)
unnamed: D8.1 (K), Q3.1 (G), R27.2, U11.3
unnamed: D9.2 (A), D10.2 (A), Q3.2 (D), Q4.3 (S), Q5.3 (S)
unnamed: D10.1 (K), D12.2 (A), Q5.1 (G), R29.2
unnamed: D9.1 (K), D11.2 (A), Q4.1 (G), R28.2
unnamed: C27.1, D11.1 (K), Q5.2 (D), T2.1 (PR1)
unnamed: C27.2, D12.1 (K), Q4.2 (D), T2.3 (PR2)
unnamed: D21.2 (A), R36.2
unnamed: D22.2 (DIN), R41.2
unnamed: F1.1, J3.1, J3.2
unnamed: J9.2, R40.2, U15.6 (CANL)
unnamed: J9.3, SW3.1, U15.7 (CANH)
unnamed: Q1.2 (D), T1.1 (PR1)
unnamed: Q2.2 (D), T1.3 (PR2)
unnamed: Q6.3 (D), R37.1
unnamed: Q7.3 (D), R38.1
unnamed: R1.2, R5.2, U4.1
unnamed: R5.1, R6.2
unnamed: R8.1, R9.2
unnamed: R24.1, U11.1
unnamed: R25.2, U11.2
unnamed: R26.1, U11.4
unnamed: R40.1, SW3.2
unnamed: L1.2, T2.2 (PM)
unnamed: C30.2, J8.1, J8.2, T2.4 (S1)
unnamed: C30.1, J7.1, J7.2, T2.5 (S2)
unnamed: U1.7 (MCLK), U5.1 (MCLK1)
unnamed: U1.6 (MDAT), U5.2 (MDAT1)
unnamed: C2.1, U2.1 (K), U2.8 (REF), U4.2
unnamed: C4.1, U3.5 (CT)
unnamed: R2.1, U3.6 (RT)
unnamed: C8.1, R7.1, R11.2, U6.3 (+)
unnamed: C10.1, R10.1, R12.2, U6.2 (-)
unnamed: C13.1, R22.1, R23.2, U6.5 (+), U9.1 (K), U9.8 (REF)
unnamed: C8.2, R11.1, U6.6 (-), U6.7
unnamed: R13.1, R14.2, U7.8 (REF)
unnamed: R21.2, U8.10 (OE)
unnamed: R34.1, U13.25 (RXD)
unnamed: R35.1, U13.12 (SUSPEND)
unnamed: R33.1, U13.26 (TXD)
unnamed: C25.1, R30.2, R32.1, U13.8 (VBUS)
unnamed: R31.1, U13.9 (~RST)
unnamed: R39.2, U15.8 (S)
RTS: Q6.2 (S), Q7.1 (G), U13.24 (~RTS)
TL494_DTC: C5.2, R3.2, R4.1, U3.4 (DTC)
TL494_E1: R17.1, U3.9 (E1)
TL494_E2: R16.1, U3.10 (E2)
TL494_VFB: R8.2, TP1.1, U3.16 (2IN+), U4.3
TL494_VREF: C5.1, R3.1, U3.2 (1IN-), U3.13 (OUTCTRL), U3.14 (REF), U3.15 (2IN-)
U0RXD: R33.2, U14.36 (RXD0)
U0TXD: R34.2, U14.37 (TXD0)
USB_DN: D19.1 (K), J5.2 (D-), U13.5 (D-)
USB_DP: D15.1 (K), J5.3 (D+), U13.4 (D+)
VCC_OUT: C3.1, C6.1, C7.1, C9.1, C11.1, C16.1, C19.1, C26.1, C35.2, D6.1 (K), D7.1 (K), D18.1 (K), D22.3 (VDD), R1.1, R39.1, U1.8 (VDD2), U5.18 (VDD), U8.19 (VCCB), U12.3 (VIN), U15.3 (VCC)
VDD1_RS1V: C1.1, C17.1, C20.1, C21.1, R23.1, U1.1 (VDD1), U6.8 (V+), U10.2 (VOUT)
V_TEMP_OUT: D5.1 (K), R20.2, U1.2 (VIN+)

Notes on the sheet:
FT50-75 Toroid. 1:2 10 Turns, 1 strand, 18AWG. 2:3 10 Turns, 1 strand, 18AWG. 5:4 2 Turns, 1 strand, 18AWG. Dot on 1 2 and 5.
Low-pass filter time constant: 0.1s
GPIO19 and GPIO20 connect to the built-in USB programmer of ESP32S3 chip. The CP2102 USB to UART chip is not needed in production.
Adjustable Resistor Pair. Tune resistance values until VFB ~= 5V when VCC_OUT is 5.1V~5.5V. Small-signal analysis TBD in LTSpice.
Selectable 120R Terminal Resistor.
V(LS)=2.5V Common-mode range: 2V~VCC_OUT.
Push-Pull (Half Bridge) Output
CTR: 200%~400%
Junction should be put close to ADC for Better Temperature Compensation.
CTR: 100%~200%
TL494 is an OG chip, can be replaced with new ICs like SG3525, etc. However TL494 is still the most widely used DC/DC chip even today. Because it is cheap and reliable.
E24 Resistor Series.
Because of leakage inductance, VDS should be at least 3x~4x +36V.
Removable 0R for debugging purposes.
Isolated ADC (Sigma-Delta ADC) and SPI interface.
Simulated in LTSpice.
10mA is the ideal working current for photocoupler primary side. Check CTR curve on the datasheet for more info.
Emitter-Follower Configuration.
K-Type Thermocouple Metal A.
ESP32S3 USB/CAN/WiFi/BLE
<=2.5V+Vf~=3.6V
FT50-43 Toroid. L1 6 Turns, 5 strand, 18AWG.
FT140-61 Toroid. 1:2 5 Turns, 3 strands, 18AWG. 2:3 5 Turns, 3 strands, 18AWG. 5:4 25 Turns, 1 strands, 18AWG. Dot on 1 2 and 5.
Temperature Sense
LittelFuse Low Profile MINI® Fuses Rated 58V. Color Code: Red 10A.
<=2.5V
Soft start ~1ms
V(OUT)=V(TC)*(R(F)/R(G))+V(LS)=100*V(TC)+2.5V
Baxandall Oscillator
Auto Program DTR RTS --> EN IO0 1 1 1 1 0 0 1 1 1 0 0 1 0 1 1 0
Use TL082H as the op-amp placeholder. In real design it has to be a precision op-amp. V(offset)<100uV if available. Recommended to use thermocouple IC like AD8495 and replace this part. This is a demo differential op-amp circuit, not practical.
2.5V
Isolated Push Pull DC/DC Converter
I(R8)=14mA I(R9)=4mA I(OPTO_12)~=10mA I(OPTO_34)~=10~20mA
Polymer Capacitors if possible.
K-Type Thermocouple Metal B.

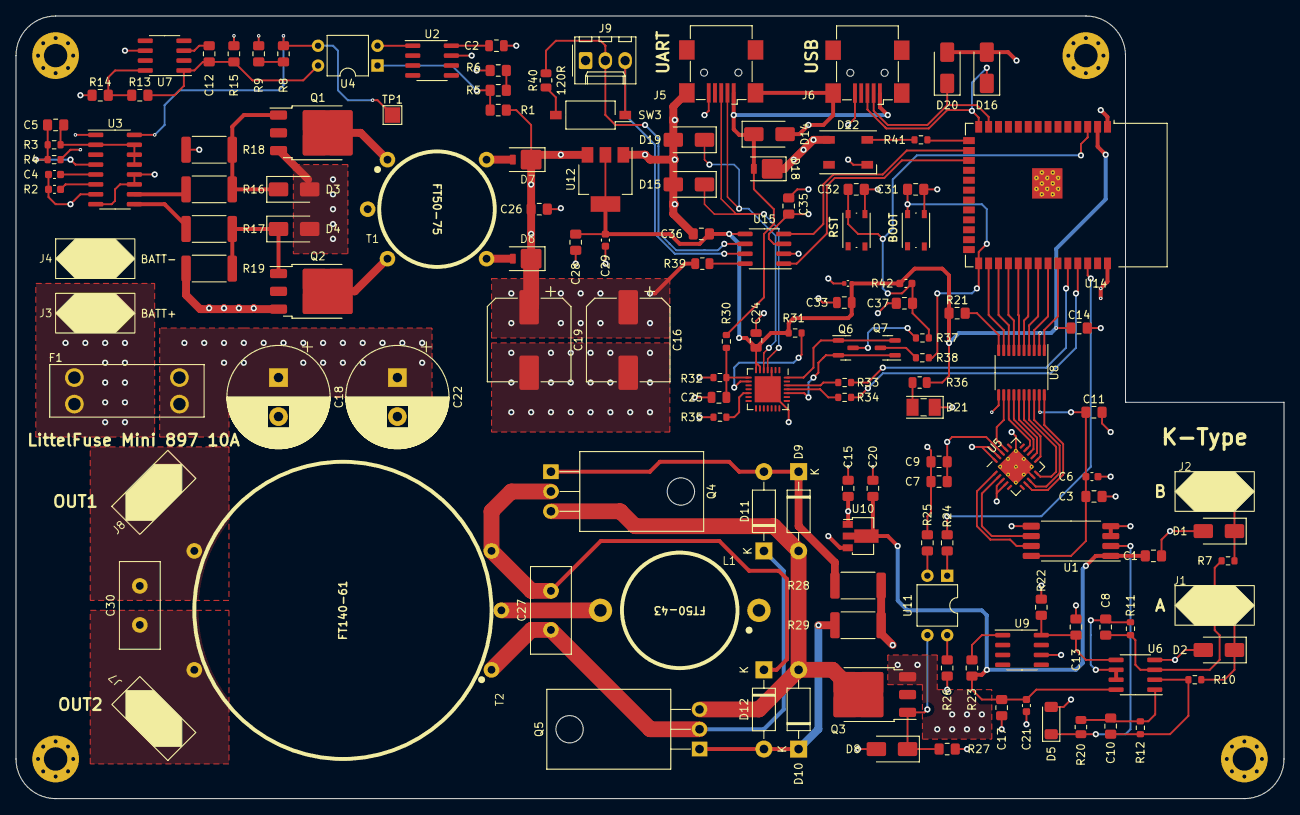
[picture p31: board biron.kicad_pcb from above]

Board: 4 copper layers, 162.6 x 100.3 mm, 141 parts (0 on the bottom side), 93 nets.

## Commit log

2023-03-25 Update PCB
    [3-1734035-2.stp, 3557-2.step, 3D_model_0891000_LP_MINI_58V.stp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]
2023-03-25 Update Text
    [biron.kicad_pcb]
2023-03-25 Update PCB silkscreen
    [biron.kicad_pcb]

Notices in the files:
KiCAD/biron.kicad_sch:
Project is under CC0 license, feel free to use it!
